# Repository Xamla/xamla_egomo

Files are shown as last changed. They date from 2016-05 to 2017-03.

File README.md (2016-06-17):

# xamla_egomo

### What is Xamla Egomo?

Egomo is an open-source research vision sensor developed at [Xamla](http://www.xamla.com/) for adaptive robotics research on a [Universal Robot UR5](http://www.universal-robots.com/) equipped with [Robotiq](http://robotiq.com/) end-of-arm technology. It integrates consumer cameras like the Logitech C920 and Structure IO and allows you to mount them on a robotic arm. It acts as a low-cost, 3D-printable reference smart-sensor device for our [ROSVITA](http://www.xamla.com/rosvita/) robot programming IDE which is currently under development (to be released in 2017).
For more information and product pictures visit the [egomo website](http://xamla.com/egomo).  

Video: Watch our UR5 robot [stacking duplos](https://www.youtube.com/watch?v=uo04vuXcwlw) using the Egomo sensor (source code of the demo can be found [here](/egomo_demos/duplo_stacking)).

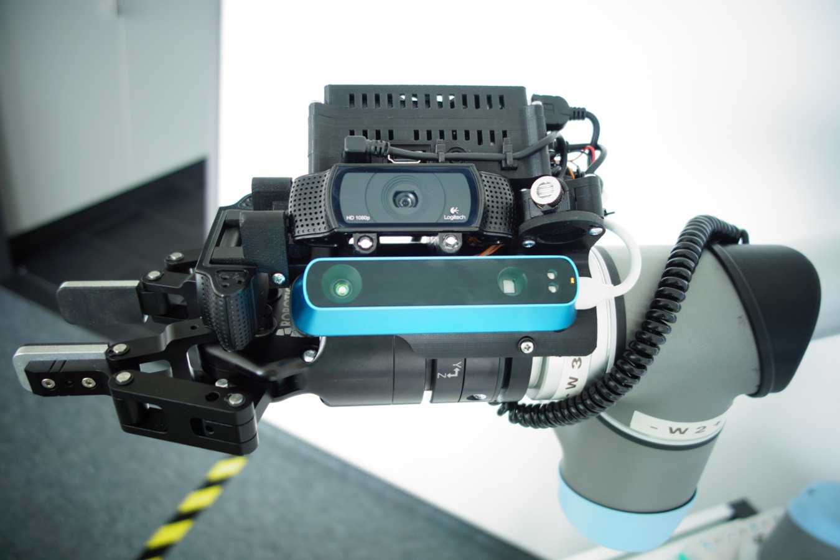
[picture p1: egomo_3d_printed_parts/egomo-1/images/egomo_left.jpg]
sensorhead1 Egomo sensor head side view, showing that the webcam can be mounten on the side as well as in the front.


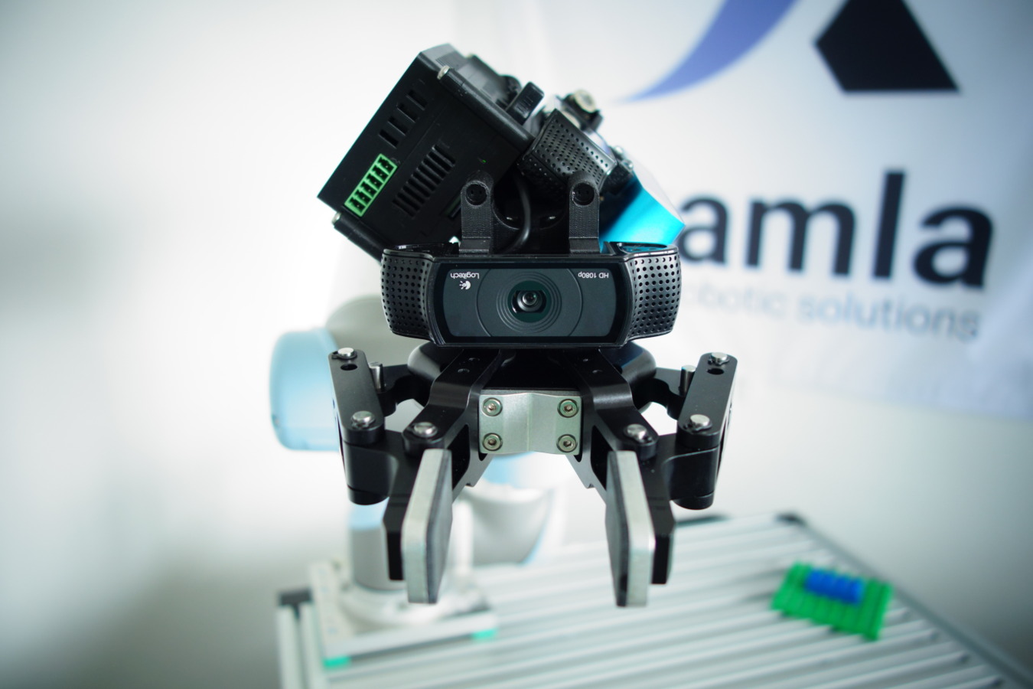
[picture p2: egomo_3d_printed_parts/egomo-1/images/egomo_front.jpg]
sensorhead2 Egomo sensor head front view


### Unique Features of Xamla Egomo

* 2D+3D: two side- and front view Logitech C920 cameras in combinaton with a structure IO depth sensor, ideal for RGB-D scans and visual servoing experiments
* NO CABLES: wireless connection of all sensors and and the gripper (no cabled device offers more available joint-configuration space)!
* ROS: the functionalty of all sensors + actuators is exposed as ROS nodes
* EASY: A Lua client library is included which allows to capture images and move the robot to capturing poses + demos are provided
* The IO-board allows to directly connect a Robotiq 2-Finger-Gripper and a Robotiq FT-300 force torque sensor to Egomo. It also has IO ports for laser, high-power white/IR LEDs, simple grippers or tactile sensors (e.g. force-sensitive resistors).
* Egomo seamlessly integrates with the [Torch](http://torch.ch/) machine-learning framework (e.g. for deep learning based image segmentation, object detection or advanced RL-experiments).

### Xamla Egomo sensor head ROS Package ###

This package is based on [LUA](https://www.lua.org/) with [Torch](http://torch.ch/) and the wrappers
[torch-ros](https://github.com/Xamla/torch-ros),  [torch-pcl](https://github.com/Xamla/torch-pcl)  and [torch-opencv](https://github.com/VisionLabs/torch-opencv).

This packages comprises (in alphabetical order):

  * [egomo_3d_printed_parts](/egomo_3d_printed_parts): STL files for printing the mounting parts and case of the Egomo sensor.
  * [egomo_demos](/egomo_demos): Demos showing the sensor in action (like pick and place objects).
  * [egomo_depthcam](/egomo_depthcam): Contains a ros-node for the Strucure-IO depth sensor.
  * [egomo_ioboard](/egomo_ioboard): Contains the specs and pinout of the Xamla IO board.
  * [egomo_msgs](/egomo_msgs): ROS Messages, Services, Actions in order to talk to Gripper, Force-Torque Sensor, RGB-Camera, Depth-Camera, Laser, LED
  * [egomo_node](/egomo_node): A ros-node which is responsible for the communication to the IO-Board (e.g. Gripper, Force-Torque, LEDs, Laser).
  * [egomo_pi_image](/egomo_pi_image): Describes the steps required to download and setup our fast booting Raspberry PI linux image.
  * [egomo_tools](/egomo_tools): A client library offering an easy to use interfaces to gripper, structure IO, webcam and the robot itself.
  * [egomo_ur5](/egomo_ur5): Contains URDF Robot description of the UR5 equipped with Egomo sensor head as well as launch files for e.g. gazebo.
  * [egomo_webcam](/egomo_webcam): Contains ros-node for the Logitech C920 webcam.
  * [xamla_egomo](/xamla_egomo) Metapackage

### Calibration ###

We offer an implemented calibration routine [on request](http://xamla.com/en/contact/index.html) as well as CAD-Files when you would like to adapt the sensor head for another robot. In 2017 we will offer [ROSVITA](http://xamla.com/en/rosvita/index.html) which brings a lot of features such as a convenient calibration routine (including full robot calibration).

### Get a pre-assembled Egomo device

You like the idea of open-source hardware but the process of buying parts, 3D printing, soldering, building etc. is too cumbersome and time-intensive for you and you would like to get a tested/working sensor head quickly?
As a convenient solution we offer a pre-assembled version of the Egomo sensor head with all parts installed and tested (good quality 3D printed parts made from ABS Ultrat, Logitech C920 Web-Cam (2x), Structure IO sensor, white LEDs (3x), IR LED, Raspberry Pi 3, Xamla IO-Board, shortened USB cables, a customized RPi operating system on a 16 GB class 10 microSD card and a 20mW 830nm IR line laser (depending on your country's import restrictions)) for EUR 1499 + shipping. If you are interested in this offer please contact us via [E-mail](mailto:egomo@xamla.com).

### Support / Contact ###

If you have any trouble please let us know by [creating an issue](https://github.com/Xamla/xamla_egomo/issues/new). Do not hesitate to contact us via [E-mail](mailto:egomo@xamla.com) for questions, feedback and suggestions. We look forward to hear from you!

To stay always up-to-date about our latest developments you can follow [@xamla on Twitter](https://twitter.com/xamla) or [subscribe](http://xamla.com/en/egomo) to our newsletter.

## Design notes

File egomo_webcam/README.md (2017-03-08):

*

This package provides an ROS interface to the Logitech C920 web camera. It uses video4linux for communication and therefore should work with other cameras supported by video4linux, too.

** Advertised Services

*** get\_new\_image
Grabs a new image from the camera. It is guaranteed that the image is recorded after this service is called. The image is provided in the camera raw format (uncompressed YUYV image in case of C920) and returned as a ROS [sensor_msgs/Image.msg](http://docs.ros.org/api/sensor_msgs/html/msg/Image.html) message.

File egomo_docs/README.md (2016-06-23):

The "index.html" visually describes the Xamla Egomo sensor head assembly. <br />
In more detail the following steps are described:

* Removal of old wrist joint cap and assembly of new one. 
* Dismantling of the Logitech camera. 
* Attachment of laser, Structure IO and Logitech camera to the printed base board. 
* Attachment of the Raspberry Pi 3 to the base board. 
* Attachment of force torque sensor, gripper and base board to the UR5. 
* Preparation of the Logitech camera for an alternative front connection with the base board.
* Alternative rotated attachment of the force torque sensor and gripper to the UR5.

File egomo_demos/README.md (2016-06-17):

# Demos for egomo sensor
This directory contains two demos that use the egomo sensor head.
- Clear Table
- Adaptive Duplo Stacking

### Clear Table
The robot identifies objects located on a table which it automatically collects and drops into a box ([Video](https://youtu.be/jR7Gnce9xus)).

### Adaptive Duplo Stacking
The robot detects freely positioned Duplo bricks on a table and stacks them on a visually measured target position ([Video](https://youtu.be/uo04vuXcwlw)).

## Calibration
These demos require very precise information about the geometric properties of the cameras ([intrinsic parameters](https://en.wikipedia.org/wiki/Camera_resectioning#Intrinsic_parameters)) and their mounting positions+orientations with respect to the tool center point (TCP) (hand-to-eye matrices). For an accurately working system these parameters have to be calibrated individually for each camera / egomo sensor. To run the demo without this complex calibration step, we added default values. Without proper calibration you should be able to see the basic behavior but not as precise as it is shown in the demo videos. 

A fully autonomous calibration procedure is in development. If you are interested to get the status or a preview version of the calibration that makes your UR5 + Egomo really accurate, please [contact us](mailto:egomo@xamla.com).

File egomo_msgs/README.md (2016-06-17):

# egomo_msgs Package #

This ROS package has to be built and installed on the Raspberry Pi which is part of the Egomo sensor 
as well as on any machine which makes use of these messages, actions and services. 
More information can be found in the [documentation of the egomo_node](https://github.com/Xamla/xamla_egomo/tree/master/egomo_node).

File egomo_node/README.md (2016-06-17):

# xamla_egomo_node #

## General Information ##

This node runs on the Raspberry Pi on the Egomo sensor and offers a ROS-service which offers ROS-actions to asynchronously control a connected gripper. Furthermore different topics are offered in order to get information about the gripper, force torque (FT) and inertial measurement unit (IMU).

### Overview  ###

 *  [Gripper message](#XamlaGripper)
 *  [Joint state of the gripper](#XamlaGripperJointState)
 *  [Force Torque message](#XamlaForceTorque)
 *  [Message IMU](#XamlaIOIMU)
 *  [Send commands to IO-Board](#SendCommand)
 *  [Action for gripper activation](#EgomoGripperActivate)
 *  [Action for setting gripper position](#EgomoGripperPos)
 *  [Troubleshooting](#Troubleshooting)

### Topic XamlaGripper ###

Publishes the state of the gripper using [XamlaGripper.msg](https://github.com/Xamla/xamla_egomo/tree/master/egomo_msgs/msg). Subscribe by typing the following in your terminal:

    rostopic echo /XamlaEgomo/XamlaGripper

Published data | type
---------|-----------
header   | [std_msgs/header](http://docs.ros.org/jade/api/std_msgs/html/msg/Header.html)
grip_force | float32
left_finger_force | float32
right_finger_force | float32
pos_fb | float32
uint8 | state
bool | object_gripped

### Topic XamlaGripperJointState ###

Publishes the state fo the gripper as joint state messages ([JointState](http://docs.ros.org/jade/api/sensor_msgs/html/msg/JointState.html)). Subscribe by typing the following in your terminal:

    rostopic echo /joint_states

Published data | type
---------|-----------
header   | [std_msgs/header](http://docs.ros.org/jade/api/std_msgs/html/msg/Header.html)
name     | string[]
position | float64[]
velocity | float64[]
effort | float64[]

### Topic XamlaForceTorque ###

Publishes sensor readings of the force torque sensor using [WrenchStamped](http://docs.ros.org/jade/api/geometry_msgs/html/msg/WrenchStamped.html). Subscribe by typing the following in your terminal: 

    rostopic echo /XamlaEgomo/XamlaForceTorque

Published data | type
---------|-----------
header   | [std_msgs/header](http://docs.ros.org/jade/api/std_msgs/html/msg/Header.html)
wrench   | [geometry_msgs/Wrench](http://docs.ros.org/jade/api/geometry_msgs/html/msg/Wrench.html)

### Topic XamlaIOIMU ###

Publishes sensor readings of the inertial measurement unit (IMU) using [AccelStamped](http://docs.ros.org/jade/api/geometry_msgs/html/msg/AccelStamped.html). Subscribe by typing the following in your terminal: 

    rostopic echo /XamlaEgomo/XamlaIOIMU

Published data | type
---------|-----------
header   | [std_msgs/header](http://docs.ros.org/jade/api/std_msgs/html/msg/Header.html)
accel   | [geometry_msgs/Accel](http://docs.ros.org/jade/api/geometry_msgs/html/msg/Accel.html)

### Service SendCommand ###

In order to send commands to the gripper this service was created ([SendCommand.srv](https://github.com/Xamla/xamla_egomo/tree/master/egomo_msgs/srv)). The following commands are available:

Command | value range | description
---------|-----------|--------------
reset   | 0 or 1 | Resets the gripper when value is set from 1 -> 0 (falling edge)
max_speed | 0-255 | Controls the speed of the gripper
max_force | 0-255 | Controls the force of the gripper
pos_cmd | 0.0-0.087 | Moves the gripper to the position (in m)
out0 | 0 or 1 | Turns on/off device at this board output (e.g. led, ir-led ord laser)
out1 | 0 or 1 | Turns on/off device at this board output (e.g. led, ir-led ord laser)
out2 | 0 or 1 | Turns on/off device at this board output (e.g. led, ir-led ord laser)

Notice that you should reset the gripper before use. During initialization the gripper moves. Here are two examples of valid calls of the service from the terminal.

    rosservice call /XamlaEgomo/SendCommand "reset" 0
    rosservice call /XamlaEgomo/SendCommand "pos_cmd" 0.05
    rosservice call /XamlaEgomo/SendCommand "out0" 0

### Action EgomoGripperActivate ###

This action can be used to activate/deactivate the gripper ([EgomoGripperActivate.action](https://github.com/Xamla/xamla_egomo/blob/master/egomo_msgs/action/EgomoGripperActivate.action)). It gives feedback about whether the gripper has been activated.

#### Goal ####

name | type | description
---------|-----------|---------------
activate   | bool | true to activate gripper - false to deactivate gripper

#### Feedback ####

name | type | description
---------|-----------|---------------
is_activated   | bool | true if gripper is activated - false if gripper is deactivated

#### Result ####

name | type | description
---------|-----------|---------------
is_activated   | bool | true if gripper is activated - false if gripper is deactivated

### Action EgomoGripperPos ###

This action can be used to send the gripper position commands ([EgomoGripperPos.action](https://github.com/Xamla/xamla_egomo/blob/master/egomo_msgs/action/EgomoGripperPos.action)). Furthermore the speed and the force can be set directly if needed. The feedback and the result contain the current position of the gripper and whether an object has been gripped.

#### Goal ####

name | type | description
---------|-----------|---------------
goal_pos   | float32 | The desired position in m (e.g. 0.0 for close or 0.087 for open)
set_speed_and_force | bool | If true the given speed and the force are set directly with the position command.
speed | uint8 | Speed of the gripper (0 is lowest, 255 is highest speed)
force | uint8 | Force of the gripper (0 is lowest, 255 is highest force)

#### Feedback ####

name | type | description
---------|-----------|---------------
pos_fb   | float32 | The current position of the gripper
object_gripped   | bool | True if an object has been gripped and false otherwise

#### Result ####

type | name | description
---------|-----------|---------------
pos_fb   | float32 | The current position of the gripper
object_gripped   | bool | True if an object has been gripped and false otherwise

## Troubleshooting FAQ

 - Q1: I get the error "No device could be found!!!".
 - A1: The IO-Board connected the the Raspberry Pi could not be found. Make sure that it is connected properly. Usually the IO-Board should be recognized by the Raspberry Pi as a device /dev/ttyACM0 or any other number.

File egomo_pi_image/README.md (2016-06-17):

# Setup the Raspberry Pi for Xamla Egomo

This how-to assumes you use a Linux PC and was tested with Ubuntu 14.04 and 16.04 but should work for other Linux distributions, too.
It describes how to setup the SD card for the Raspberry Pi and provides a short overview how to operate the system.

## Prepare the SD card for the Raspberry Pi

The egomo sensor image for the Raspberry Pi can be obtained from the [Xamla homepage](http://xamla.com/downloads/egomo-1/rpi/xamla-egomo_v1_0.tar.gz). It is based on `Raspbian Jessie Lite`, version `May 2016`. In addition to the default image it contains amongst others a Lua+Torch installation, a basic ROS Jade installation and the Xamla Egomo tools. The image is optimized for fast boot and operates on read only partitions to protect the file system in case of a power failure.

The image can be installed to any SD card supported by the PI with a size of at least 8 GB. To achieve a short boot time and good operation performance of the Pi we recommend using class 10 SD cards or better.

Checksums of the image:

	MD5: dcfa77735607cd9b82e2f022387f87f7  xamla-egomo_v1_0.tar.gz
	SHA256: 1cad057e50a2ecf666028fc2797ee1846d1c4cb6a63e0c153f497c6268f39edc  xamla-egomo_v1_0.tar.gz

### Copying the Image to the SD Card

These steps are very similar to the steps required to [setup the usual Raspberry Pi images](https://www.raspberrypi.org/documentation/installation/installing-images/linux.md):

* Download the [SD card image](http://xamla.com/downloads/egomo-1/rpi/xamla-egomo_v1_0.tar.gz)
  * Connect the (new) SD card with your computer (SD card slot or via an SD card reader)
  * Unmount all partitions of the SD card (e.g. unmount /dev/sdd1 if sdd is your SD card device name) if any partition got mounted automatically
  * Write the content of the .img file to the SD card, e.g.

		`sudo dd bs=4M if=/some/path/on/your/disk/xamla-egomo.img of=/dev/sdd`

	***IMPORTANT***: Make sure to provide the *correct device name* as parameter for `of`, not just one of the partitions.
	You will loose all data on the device. So, double-check if the device (/dev/sdd) is really the SD card.
  * Wait until `dd` has finished. This might take some time and you will not see any output during the operation.
	With a typical class 10 SD card, the copy process takes about 6 minutes.
  * Remove the SD card and reconnect it with your PC. You should see two partitions on the SD card:
	A small one called boot and a second one with a size of about 6 GB containing the root file system. If the partitions don't get mounted automatically, mount them manually. When the root partition of the SD card is mounted, continue with the next section.

### Adopt the Config Files for Your Network/ROS Environment

The partition on the SD card are mounted read-only during operation to protected the file system in case of power failure. Therefore a few more files then usual have to be adopted.

  * `/etc/hosts`: Adopt the hostname to your requirement
  * `/etc/hostname`: Replace `pi-xamla` with the same hostname you set in /etc/hosts
  * `/etc/resolv.conf`: Set the correct domain name and the IP address of at least one name server. Usually this file would be updated automatically but since we are running a read-only filesystem the file has been filled by hand.
  * `/etc/ros-config`: Set the `ROS_MASTER_URI` to the URI of the system running the roscore/master server
  * `/etc/ntp.conf`: If the Pi has no internet access, provide the address of at least one reachable NTP server. By default, the debian.pool NTP servers are used.
  * `/etc/wpa_supplicant/wpa_supplicant.conf` By default, the pi uses the on-board wireless adapter for network access. The SSID and the password for the WLAN has to be configured in this file. If you want to use the Ethernet port instead of wireless, edit `/etc/network/interfaces`.

## First Boot

Plug in the SD card to your Raspberry Pi and power it up.

  * Log in to the pi with username `pi` and password `xamla`. (either via network or via a directly connected keyboard/monitor)
  * Remount the partition in read-write mode. To comfortable switch between read-only and read-write mode, two aliases `ro` and `rw` are defined. Just type `rw` at the prompt to remount the partition as read-write.
  * Change the password for user pi with `passwd`.
  * You might want to regenerate the SSH server keys:

        sudo rm -v /etc/ssh/ssh_host_*
        sudo dpkg-reconfigure openssh-server

## Useful Commands

  * By default, three ROS nodes are started during the system boot. The status of the nodes can be checked with

        sudo systemctl status rosgripper.service
        sudo systemctl status roswebcam.service
        sudo systemctl status rosdepthcam.service

  * Rebuilding the catkin workspace: Switch to ~/catkin_ws and execute

        source /home/pi/catkin_ws/devel/setup.bash
        catkin_make -DCMAKE_INSTALL_PREFIX=/opt/ros/jade -DCMAKE_BUILD_TYPE=Release -DCMAKE_CXX_FLAGS=-O3 install

## Remote Logging

The current setup uses the busybox syslogd daemon. It get's configured via `/etc/default/busybox-syslogd`. Open the file
and edit the line starting with `SYSLOG_OPTS`. Comment the line `SYSLOG_OPTS="-C128"` and uncomment `SYSLOG_OPTS="-C128 -L -R host:port"`. Host and port have to be set to your remote logging host. If you use the default port 512, the port number can be omitted. Afterwards, restart the syslog daemon via `sudo systemctl restart busybox-syslogd`

On the remote logging host, uncomment/add following lines in `/etc/rsyslog.conf`

        # provides UDP syslog reception
        $ModLoad imudp
        $UDPServerRun 514
        # make rsyslog listen on all ip addresses, you could specify an address
        $UDPServerAddress 0.0.0.0

**WARNING** Configuring the remote logging this way both expose all logging messages of the Pi to all PCs in your network and exposes the logging host so that any computer in the network can send log messages to the logging host. Use this setup only in a trusted network.

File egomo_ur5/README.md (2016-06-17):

# Description of egomo_ur5 #

This package contains the kinematic chain of the full egomo_ur5 robotic setup (ur5 + force torque sensor + Robotiq gripper + egomo sensor) together with their visualization and collision models.

## General Information ##

Launch scripts are provided to start the robotic system with the URDF description
and the ros joint position controllers.

Start with real robot:

    roslaunch egomo_ur5 xamlaEgomo_ur5.launch

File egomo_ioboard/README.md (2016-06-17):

# xamla_ioboard
The Xamla IOBoard is the power supply and lowlevel IO interface of Xamla egomo.

### SPECS
- Cortex M4 CPU 72MHz
- 4x analog input 0-5V 12bit
- 3x digital output (5V 1A / 24V 1A, pwm capable)
- 6 axis IMU (MPU 6050)
- RGB LED 24bit
- 48V 1.5A input
- 5V 4A output (Sensors, RPi, ...)
- 24V 2A output (Gripper, FTS)
- USB 2.0 FS configuration port
- 2x RS485 UART max. 9Mbit/s
- 85x55mm

### PINOUT
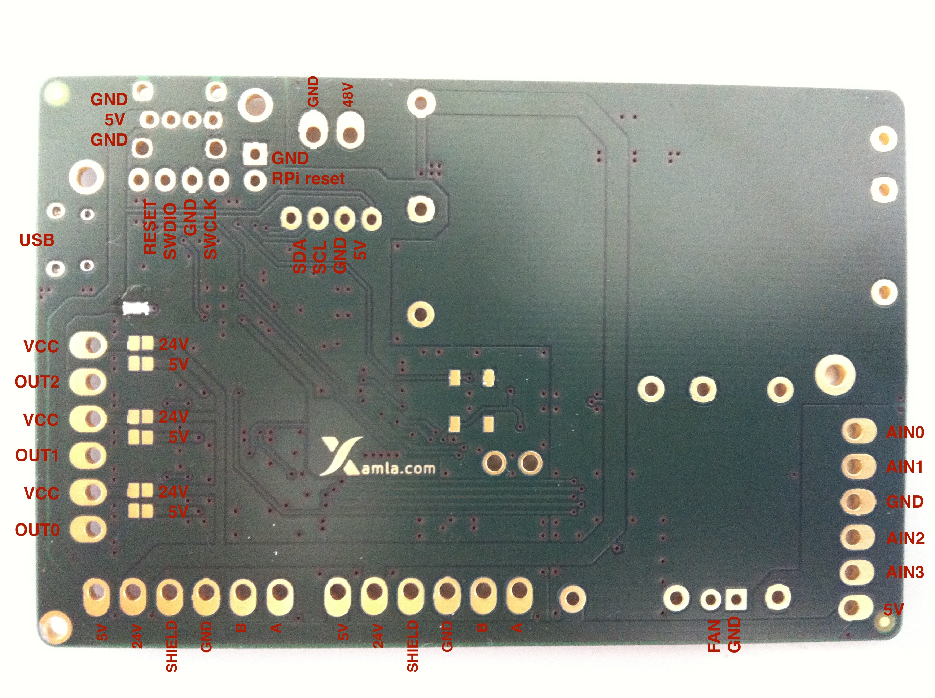
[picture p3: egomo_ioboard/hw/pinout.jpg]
ioboard_0_9_1 pinout IOBoard 0.9.1


### SCHEMATIC
[IOBoard 0.9.1 schematic](hw/io.pdf)

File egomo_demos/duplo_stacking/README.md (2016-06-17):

# Duplo Stacking Demo

## What is done?
This demo shows how to stack Duplo bricks that are placed randomly on a table. (A video of this demo is available on youtube https://youtu.be/uo04vuXcwlw ). The robot searches in a predefined area for a target brick that must be mounted on a Duplo base plate. If the target brick has been found, the robot moves to a predefined overview pose, acquires a depth image, makes a simple segmentation (object that is located above a plane), moves to a found duplo brick, acquires two rgb images and triangualtes the center position of the brick. Then the robot grips the brick and moves to the target position and stacks the brick.

## Assumptions
- The tables normal where bricks are located is (0,0,-1) (in robot base coordinates)
- Bricks are standard duplo bricks (2x4 height 19mm)
- hand-eye of depth sensor and rgb camera and their intrinsics are known
- The setup is: one brick on a base-plate as target position at a roughly known position
- bricks to be stacked are located on a flat surface 

## Package Requirements
- [torch-ros](http://github.com/xamla/torch-ros)
- [torch-opencv](https://github.com/VisionLabs/torch-opencv/)
- [torch-pcl](http://github.com/xamla/torch-pcl)
- [egomo_tools](https://github.com/Xamla/xamla_egomo/tree/master/egomo_tools)

## Code
The code consists of three parts:
- robot movement and gripping operations ([adaptiveStackingDuplo.lua](adaptiveStackingDuplo.lua))
- detection of duplo bricks ([duploDetection.lua](duploDetection.lua))
- segmentation of depth image ([ObjectsOnPlaneSegmentation.lua](ObjectsOnPlaneSegmentation.lua))

### duploDetection.lua
Idea: The knobs of the Duplo are detected in each image individually by a opencv Hough Circle detection, then circles are matched using the known fundamental matrix between the images, and triangulated. To avoid matching errors an initial guess of the z-Value (in robot coordinates) of the top edge is provided by the user. Finally, the orientation and the center of the duplo is calculated

### adaptiveStackingDuplo.lua
Idea: (Workflow can be found in [main function](https://github.com/Xamla/xamla_egomo/blob/master/egomo_demos/duplo_stacking/adaptiveStackingDuplo.lua#L279))
- Robot moves to a predefined target position (positions are defined in `CreatePoses()`), 
- the target is scanned (`ScanTargetPosition()`)
- The robot moves to an overview pose and grabs an image
- Then objects are segmented laying on the table (`segmentation:process(....)`)
- Robot moves wo the Duplo such that the camera is located above the Duplo (`ScanDuplo()`)
- If the Duplo brick is found the robot moves to a pre-pick position
- Then it gripps the brick
- Moves to target position (pre-Place position and then place postion)
- Opens the gripper
- Then the whole process is repeated

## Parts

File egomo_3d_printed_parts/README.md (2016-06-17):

# 3D-Print Your Xamla Egomo Sensor Head

You can use your favorite 3D printing service to produce the parts of an Egomo sensor head. For local 3D printing we can recommend [3D hubs](https://www.3dhubs.com/). For best quality prints (guaranteed to be accurately fitting) you can also order the parts directly [from us](mailto:egomo@xamla.com) or from our local 3D printing partner [UrbanMarker](http://urbanmaker.de/) (located in Münster, Germany).

## Available Models

- [Egomo-1](egomo-1/README.md)

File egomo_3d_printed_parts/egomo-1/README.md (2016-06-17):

# STL files for 3D printing of Egomo-1

## Product Pictures

We took some photos to give you an impression how the finished sensor head looks when it is mounted on a UR5.

Egomo left view
Egomo front view
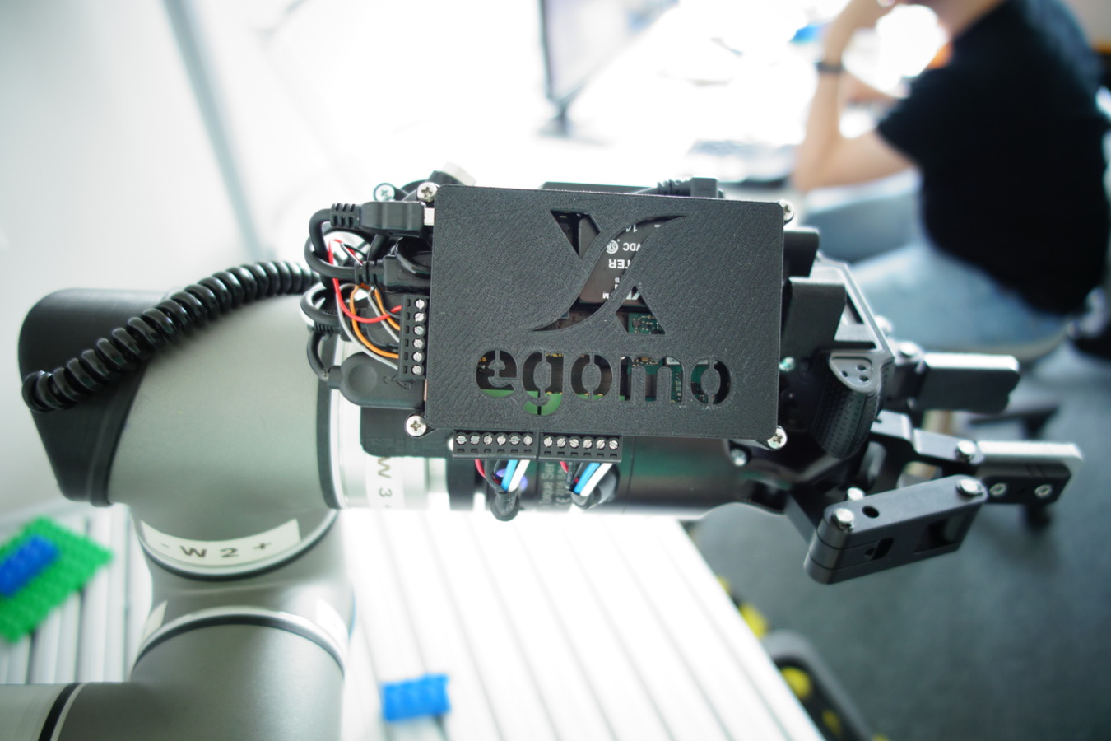
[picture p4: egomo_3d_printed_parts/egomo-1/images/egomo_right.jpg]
Egomo right view

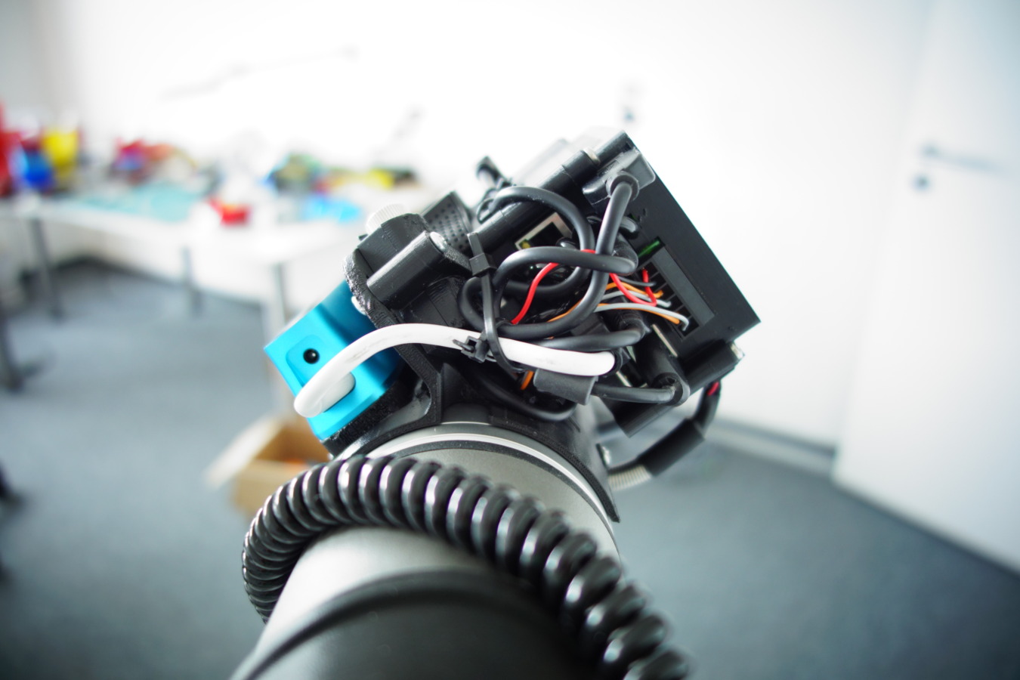
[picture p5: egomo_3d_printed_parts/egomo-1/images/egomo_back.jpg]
Egomo back view

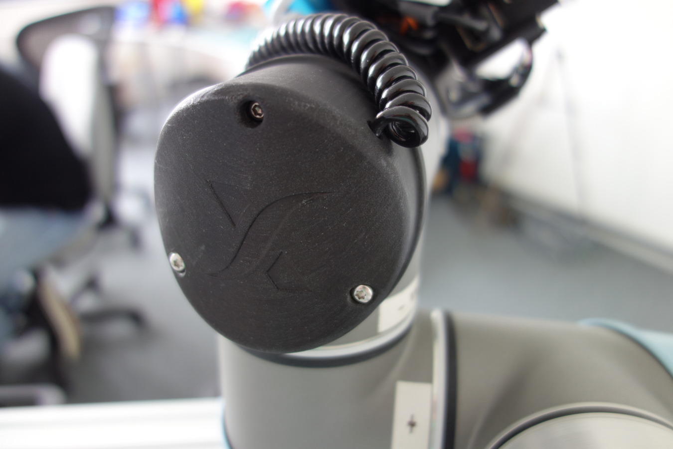
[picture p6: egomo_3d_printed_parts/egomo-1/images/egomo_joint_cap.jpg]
Egomo joint cap


## Multi-use Options

There are many ways to use the Egomo 3D models for your robotic research experiments:

Here are some ideas:

1. Obviously you can build the fully featured Egomo-1 sensor, optionally with or without enclosure for the Raspberry Pi or front-camarea mount.
2. Just use the coupling + base plate as a camera mount (conventionally cabled).
3. Use the RPi+IO-Board enclosure stand-alone as a remote ROS sensor-node or smart camera (e.g. to monitor the roboter scene from a fixed RGB-D camera). 

## Parts

The 3D printing file set of the Egomo-1 sensor consinsts of the following parts:

- coupling: [xamla_mount_flange.stl](xamla_mount_flange.stl)
- base-plate: [xamla_mount_base.stl](xamla_mount_base.stl)
- custom joint cap: [xamla_cap_hole.stl](xamla_cap_hole.stl)
- C920 side mount: [xamla_mount_c920_left.stl](xamla_mount_c920_left.stl), [xamla_mount_c920_right.stl](xamla_mount_c920_right.stl)
- C920 front mount: [xamla_mount_c920_front_0_left.stl](xamla_mount_c920_front_0_left.stl), [xamla_mount_c920_front_0_right.stl](xamla_mount_c920_front_0_right.stl) 
- Line-Laser mount: [xamla_mount_laser_bottom.stl](xamla_mount_laser_bottom.stl), [xamla_mount_laser_top.stl](xamla_mount_laser_top.stl)
- Raspberry Pi + IO Board enclosure: [xamla_mount_rpi_bottom.stl](xamla_mount_rpi_bottom.stl), [xamla_mount_rpi_middle.stl](xamla_mount_rpi_middle.stl),  [xamla_mount_rpi_top.stl](xamla_mount_rpi_top.stl)

Additionally we provide the file [xamla_cap.stl](xamla_cap.stl) which is a simple version of our modified joint cap without a hole for the power cable. It might be useful if you just want to fix a kinematic problem (collision) of the original UR5 joint cap that prevents the robot from freely rotating in all situations.

## Adaption to other Robots

If you are a robotics researcher and you want to customize the Egomo 3D parts to your special requirements or adapt it to a different robot we can provide you the original CAD files on request. Please get in touch with us via [E-Mail](mailto:egomo@xamla.com).

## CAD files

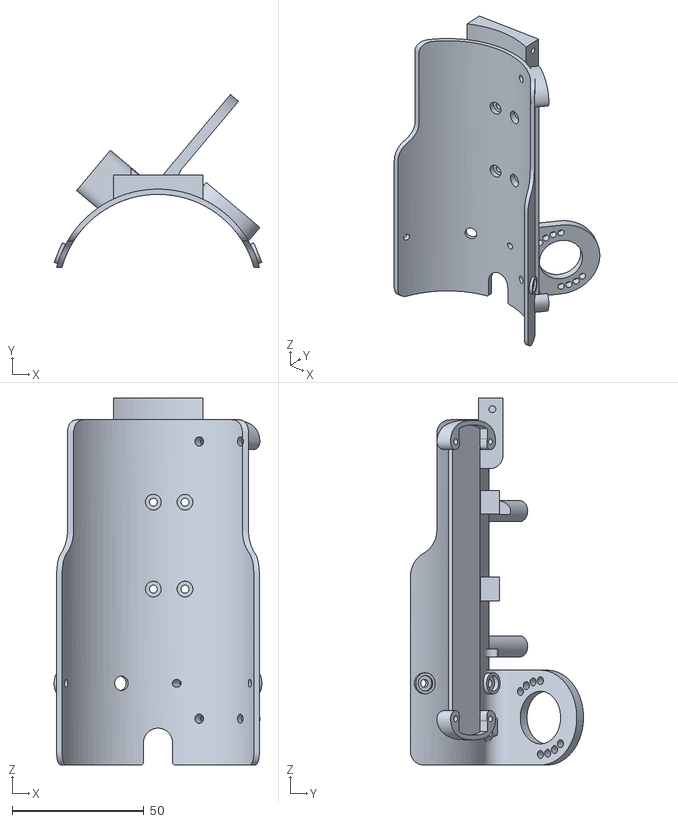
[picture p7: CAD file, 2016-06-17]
egomo_3d_printed_parts/egomo-1/xamla_mount_base.stl
78.8 x 65.6 x 139.3

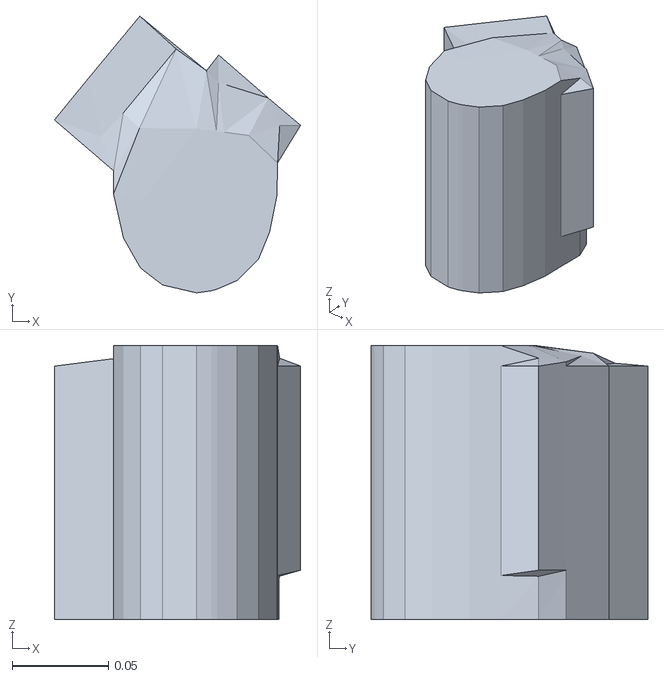
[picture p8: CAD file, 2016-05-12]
egomo_ur5/meshes/egomo-1/collision/egomo-1.stl
0.128 x 0.144 x 0.143

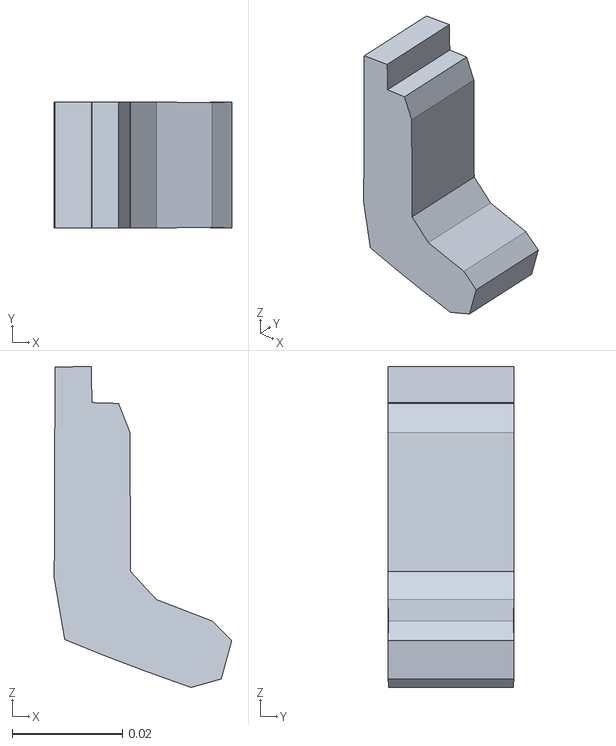
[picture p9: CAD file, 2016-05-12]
egomo_ur5/meshes/robotiq-2-finger-85/collision/gripper_finger_left_4.stl
0.0322 x 0.0228 x 0.0581

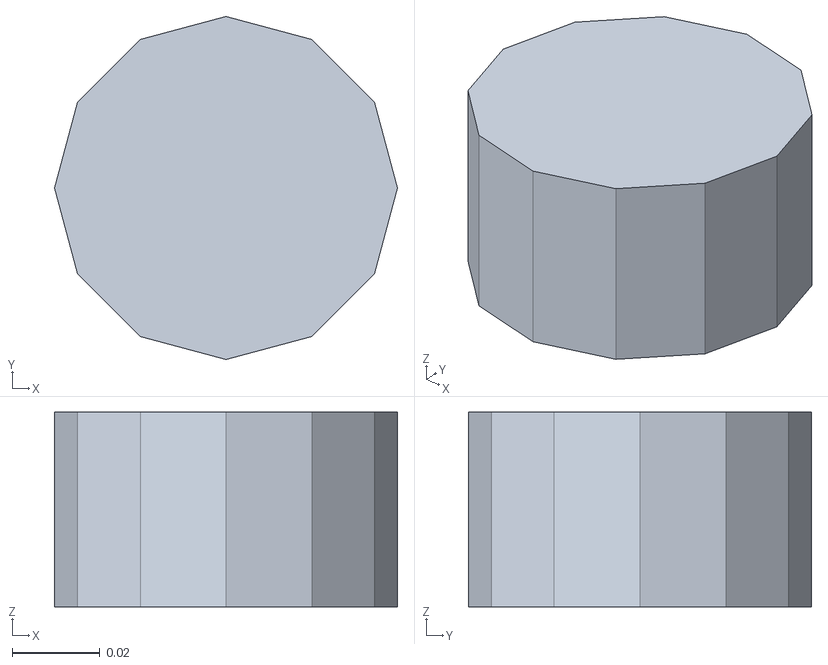
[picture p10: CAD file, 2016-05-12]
egomo_ur5/meshes/robotiq-ft300/collision/ft300.stl
0.0782 x 0.0782 x 0.0443

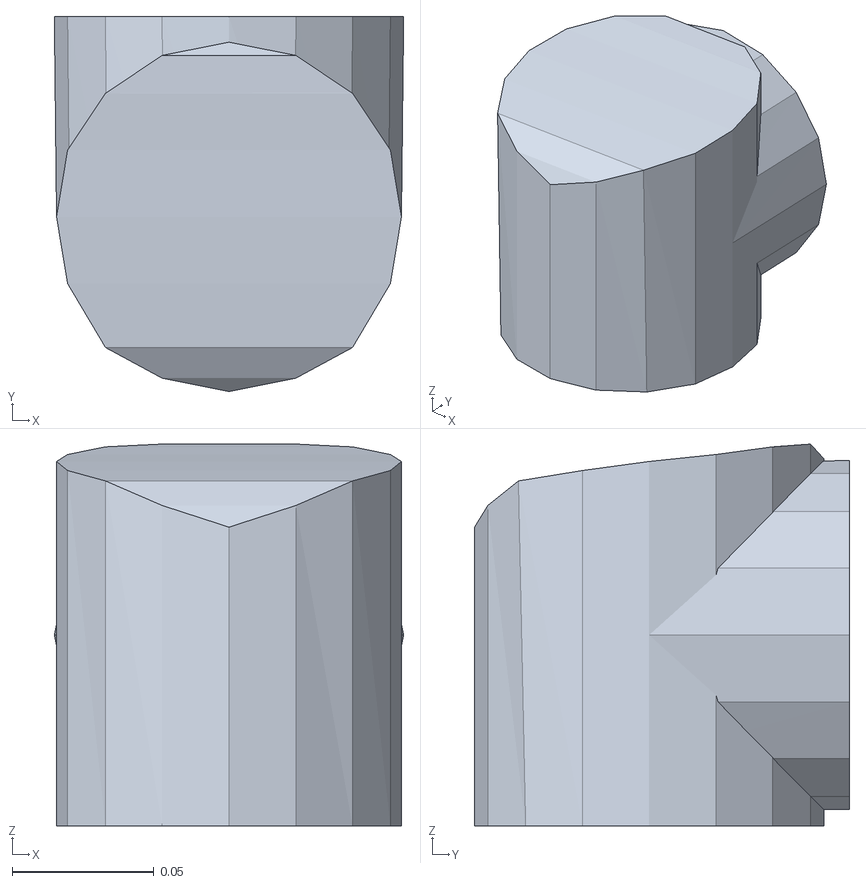
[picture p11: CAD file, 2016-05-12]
egomo_ur5/meshes/ur5/collision/shoulder.stl
0.123 x 0.132 x 0.135

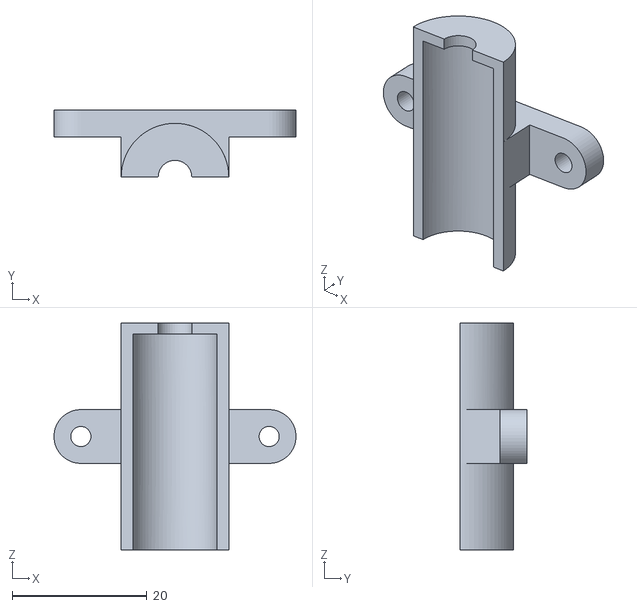
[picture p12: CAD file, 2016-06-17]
egomo_3d_printed_parts/egomo-1/xamla_mount_laser_top.stl
36.0 x 10.0 x 33.7

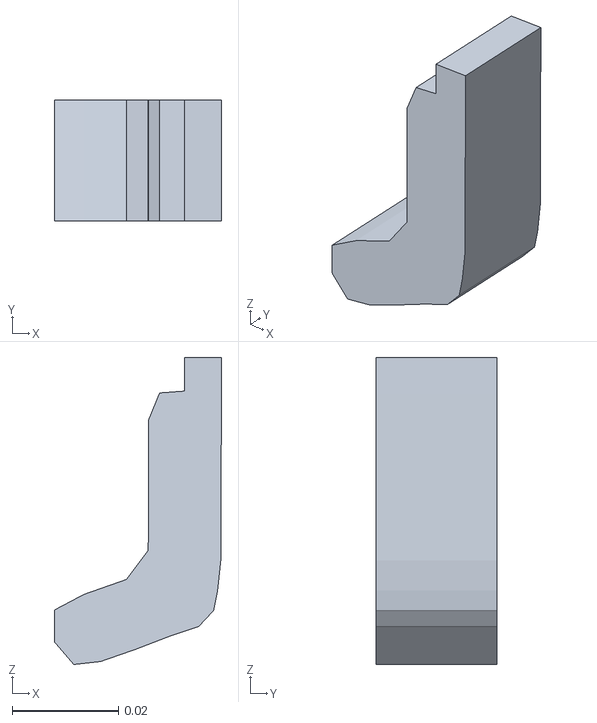
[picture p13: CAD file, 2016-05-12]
egomo_ur5/meshes/robotiq-2-finger-85/collision/gripper_finger_right_4.stl
0.0314 x 0.0228 x 0.0578

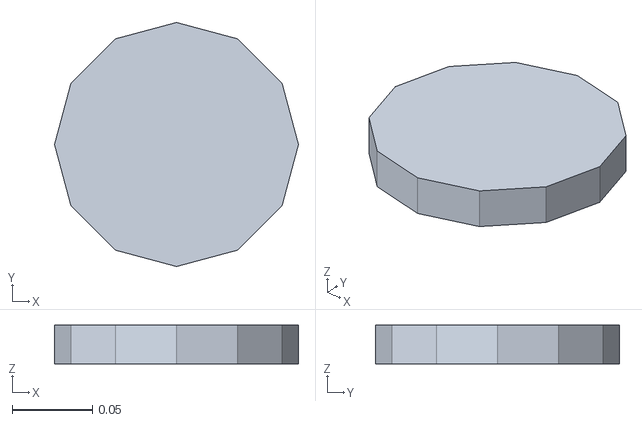
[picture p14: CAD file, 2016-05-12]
egomo_ur5/meshes/ur5/collision/base.stl
0.152 x 0.152 x 0.0242

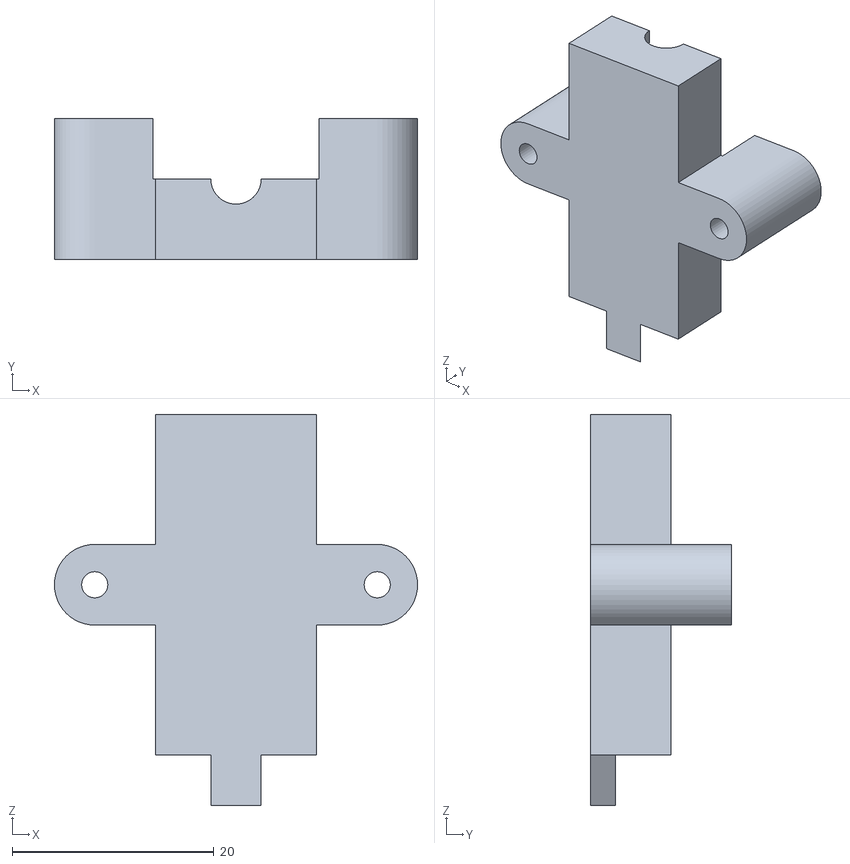
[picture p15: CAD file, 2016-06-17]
egomo_3d_printed_parts/egomo-1/xamla_mount_laser_bottom.stl
36.0 x 14.0 x 38.7

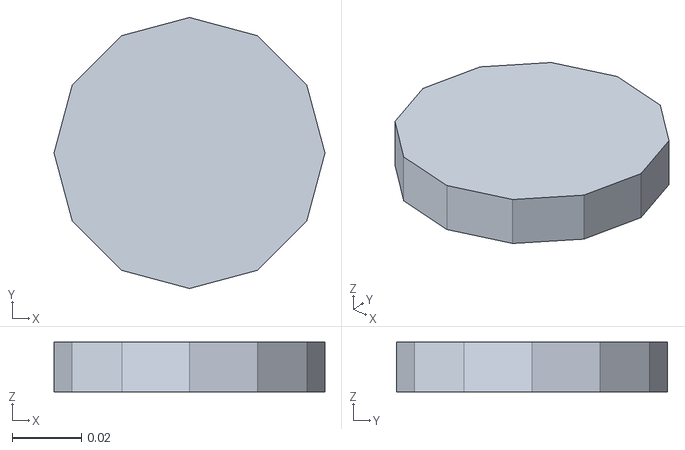
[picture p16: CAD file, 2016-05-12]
egomo_ur5/meshes/robotiq-2-finger-85/collision/gripper_coupling.stl
0.0781 x 0.0781 x 0.0143

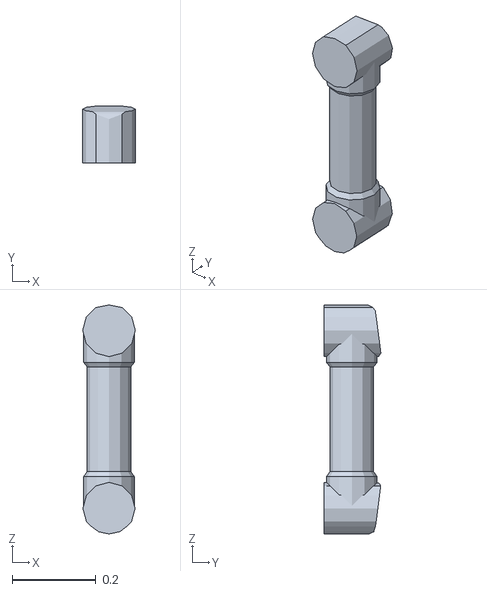
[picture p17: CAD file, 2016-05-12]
egomo_ur5/meshes/ur5/collision/upper_arm.stl
0.126 x 0.136 x 0.547

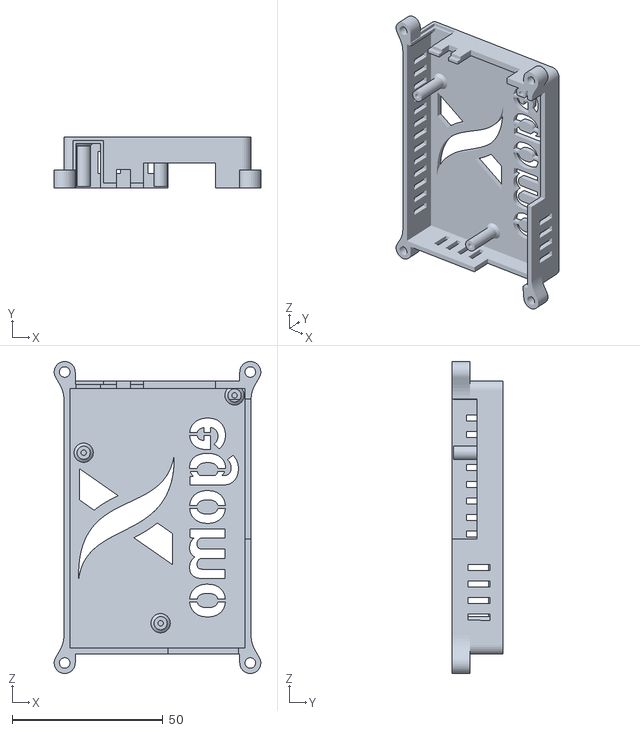
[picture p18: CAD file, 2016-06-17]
egomo_3d_printed_parts/egomo-1/xamla_mount_rpi_top.stl
68.5 x 16.9 x 103.4

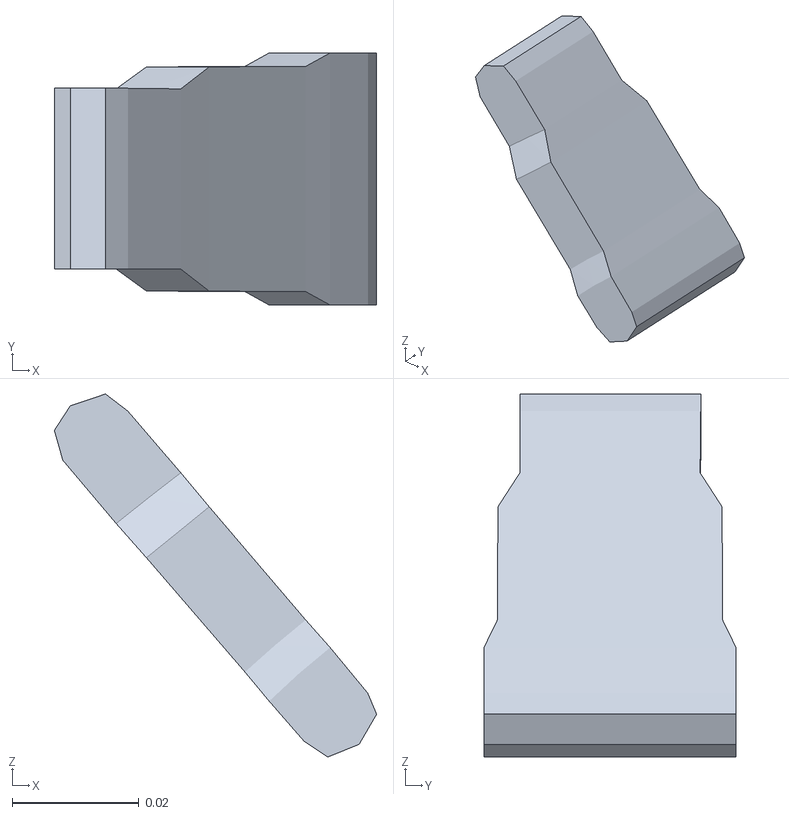
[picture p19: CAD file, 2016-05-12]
egomo_ur5/meshes/robotiq-2-finger-85/collision/gripper_finger_right_3.stl
0.0509 x 0.0398 x 0.0573

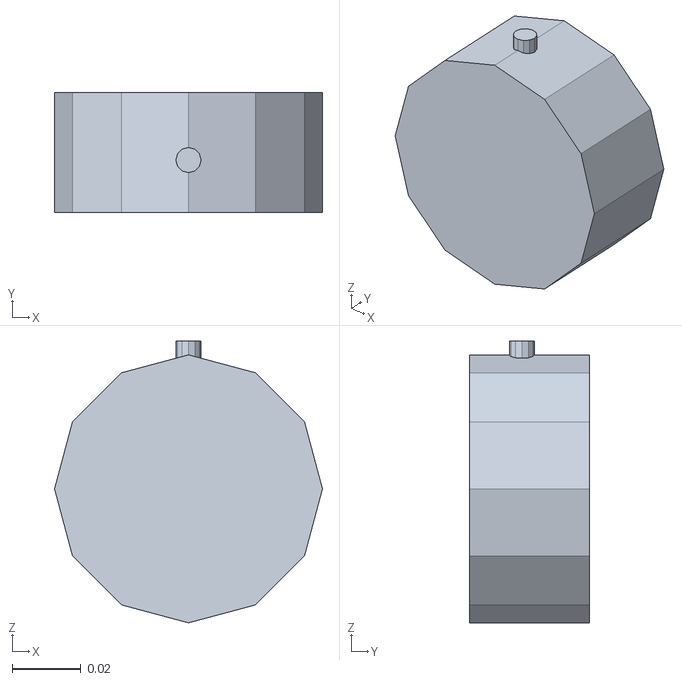
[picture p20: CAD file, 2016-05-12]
egomo_ur5/meshes/ur5/collision/wrist_3.stl
0.0781 x 0.0349 x 0.0821

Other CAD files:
egomo_3d_printed_parts/egomo-1/xamla_mount_rpi_middle.stl
egomo_ur5/meshes/robotiq-2-finger-85/collision/gripper_finger_left_1.stl
egomo_ur5/meshes/ur5/collision/wrist_2.stl
egomo_3d_printed_parts/egomo-1/xamla_mount_rpi_bottom.stl
egomo_3d_printed_parts/egomo-1/xamla_cap.stl
egomo_3d_printed_parts/egomo-1/xamla_cap_hole.stl
egomo_3d_printed_parts/egomo-1/xamla_mount_c920_front_0_left.stl
egomo_3d_printed_parts/egomo-1/xamla_mount_c920_front_0_right.stl
egomo_3d_printed_parts/egomo-1/xamla_mount_c920_left.stl
egomo_3d_printed_parts/egomo-1/xamla_mount_c920_right.stl
egomo_3d_printed_parts/egomo-1/xamla_mount_flange.stl
egomo_ur5/meshes/robotiq-2-finger-85/collision/gripper_base.stl
egomo_ur5/meshes/robotiq-2-finger-85/collision/gripper_finger_left_2.stl
egomo_ur5/meshes/robotiq-2-finger-85/collision/gripper_finger_left_3.stl
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

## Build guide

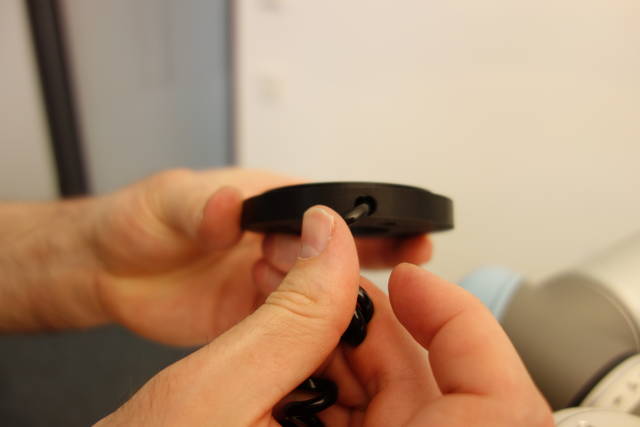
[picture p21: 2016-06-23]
egomo_docs/Egomo_Installation/small-DSC03203.JPG

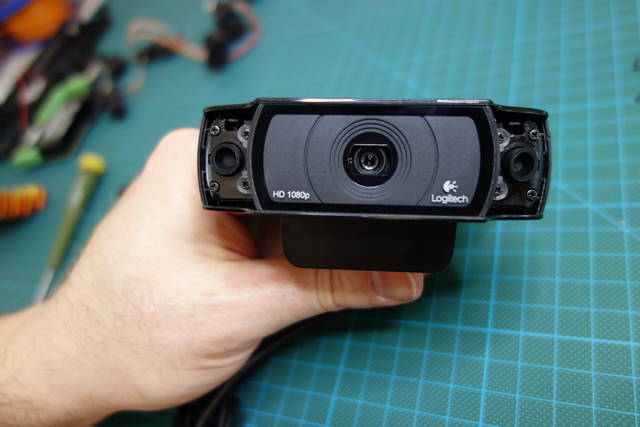
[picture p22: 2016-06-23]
egomo_docs/Egomo_Installation/small-DSC03115.JPG

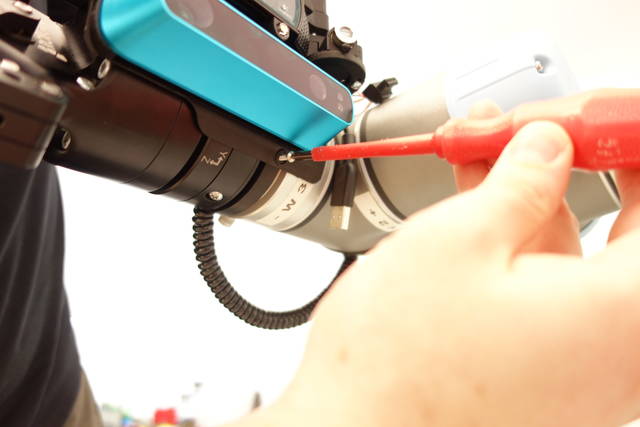
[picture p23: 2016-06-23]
egomo_docs/Egomo_Installation/small-DSC03222.JPG

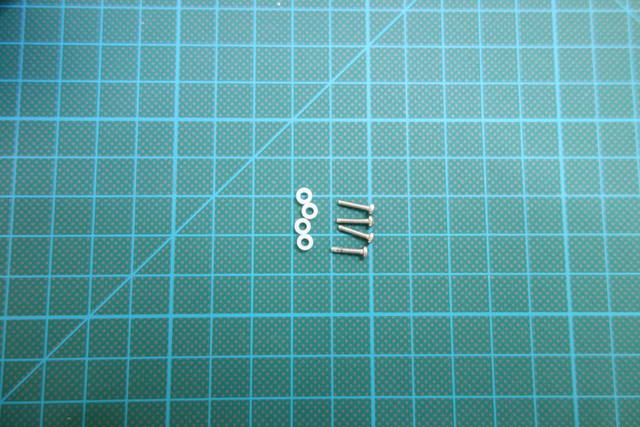
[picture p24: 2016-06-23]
egomo_docs/Egomo_Installation/small-DSC03189.JPG

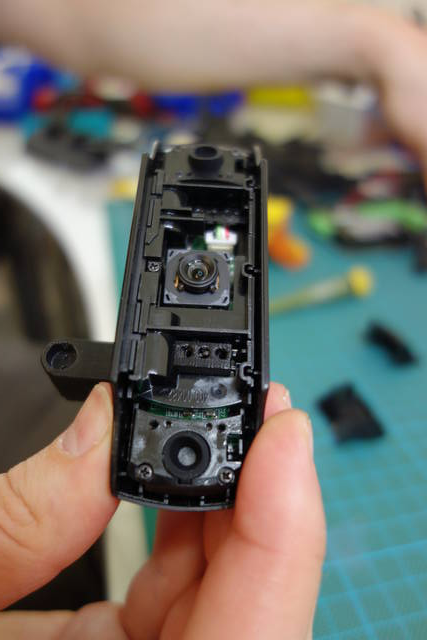
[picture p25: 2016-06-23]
egomo_docs/Egomo_Installation/small-DSC03126.JPG

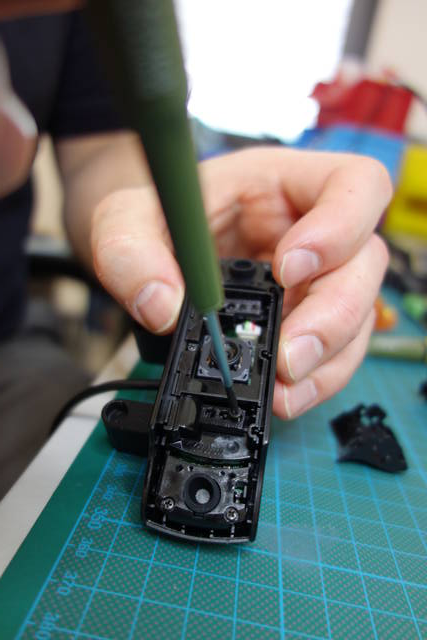
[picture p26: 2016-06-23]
egomo_docs/Egomo_Installation/small-DSC03130.JPG

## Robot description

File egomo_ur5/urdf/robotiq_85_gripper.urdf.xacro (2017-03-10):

<?xml version="1.0"?>
<robot name="robotiq_85_gripper" xmlns:xacro="http://ros.org/wiki/xacro">
    <xacro:macro name="robotiq_85_gripper" params="prefix parent *origin">
        <link name="${prefix}robotiq_85_coupling">
            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
        </link>
        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
        <joint name="${prefix}gripper_to_flange" type="fixed">
            <parent link="${parent}" />
            <child link="${prefix}robotiq_85_coupling" />
            <xacro:insert_block name="origin" />
        </joint>
        <joint name="${prefix}robotiq_85_base_joint" type="fixed">
            <parent link="${prefix}robotiq_85_coupling" />
            <child link="robotiq_85_base" />
            <origin xyz="0 0 0.0109" rpy="0 0 0" />
            <xacro:insert_block name="origin" />
        </joint>
        <link name="${prefix}robotiq_85_base">
            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
        </link>
        <link name="${prefix}robotiq_85_finger_right_1">
            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
        </link>
        <link name="${prefix}robotiq_85_finger_right_2">
            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
        </link>
        <link name="${prefix}robotiq_85_finger_right_3">
            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
        </link>
        <link name="${prefix}robotiq_85_finger_right_4">
            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
        </link>
        <link name="${prefix}robotiq_85_finger_left_1">
            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
        </link>
        <link name="${prefix}robotiq_85_finger_left_2">
            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
        </link>
        <link name="${prefix}robotiq_85_finger_left_3">
            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
        </link>
        <link name="${prefix}robotiq_85_finger_left_4">
            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
        </link>
        <joint name="${prefix}robotiq_85_finger_right_1_joint" type="revolute">
            <parent link="${prefix}robotiq_85_base" />
            <child link="${prefix}robotiq_85_finger_right_1" />
            <axis xyz="0 -1 0" />
            <origin rpy="0 0 0" xyz="0.0305864 0 0.0549191" />
            <limit effort="1000" lower="0" upper="0.811" velocity="2.0" />
        </joint>
        <joint name="${prefix}robotiq_85_finger_right_2_joint" type="fixed">
            <parent link="${prefix}robotiq_85_finger_right_1" />
            <child link="${prefix}robotiq_85_finger_right_2" />
            <axis xyz="0 1 0" />
            <origin rpy="0 0 0" xyz="0.0315367 0 -0.0037599" />
        </joint>
        <joint name="${prefix}robotiq_85_finger_right_3_joint" type="revolute">
            <parent link="${prefix}robotiq_85_base" />
            <child link="${prefix}robotiq_85_finger_right_3" />
            <axis xyz="0 1 0" />
            <origin rpy="0 0 0" xyz="0.0127161 0 0.0613987" />
            <limit effort="1000" lower="0" upper="0.811" velocity="2.0" />
            <mimic joint="robotiq_85_finger_right_1_joint" multiplier="-1" offset="0" />
        </joint>
        <joint name="${prefix}robotiq_85_finger_right_4_joint" type="revolute">
            <parent link="${prefix}robotiq_85_finger_right_3" />
            <child link="${prefix}robotiq_85_finger_right_4" />
            <axis xyz="0 1 0" />
            <origin rpy="0 0 0" xyz="0.0371331 0 0.0434428" />
            <mimic joint="${prefix}robotiq_85_finger_right_1_joint" multiplier="1" offset="0" />
            <limit effort="1000" lower="-0.811" upper="0" velocity="2.0" />
        </joint>
        <joint name="${prefix}robotiq_85_finger_left_1_joint" type="revolute">
            <parent link="robotiq_85_base" />
            <child link="${prefix}robotiq_85_finger_left_1" />
            <axis xyz="0 1 0" />
            <origin rpy="0 0 0" xyz="-0.0305864 0 0.0549191" />
            <mimic joint="${prefix}robotiq_85_finger_right_1_joint" multiplier="1" offset="0" />
            <limit effort="1000" lower="-0.811" upper="0" velocity="2.0" />
        </joint>
        <joint name="${prefix}robotiq_85_finger_left_2_joint" type="fixed">
            <parent link="${prefix}robotiq_85_finger_left_1" />
            <child link="${prefix}robotiq_85_finger_left_2" />
            <axis xyz="0 1 0" />
            <origin rpy="0 0 0" xyz="-0.0315367 0 -0.0037599" />
        </joint>
        <joint name="${prefix}robotiq_85_finger_left_3_joint" type="revolute">
            <parent link="${prefix}robotiq_85_base" />
            <child link="${prefix}robotiq_85_finger_left_3" />
            <axis xyz="0 1 0" />
            <origin rpy="0 0 0" xyz="-0.0127161 0 0.0613987" />
            <mimic joint="${prefix}robotiq_85_finger_right_1_joint" multiplier="1" offset="0" />
            <limit effort="1000" lower="-0.811" upper="0" velocity="2.0" />
        </joint>
        <joint name="${prefix}robotiq_85_finger_left_4_joint" type="revolute">
            <parent link="${prefix}robotiq_85_finger_left_3" />
            <child link="${prefix}robotiq_85_finger_left_4" />
            <axis xyz="0 1 0" />
            <origin rpy="0 0 0" xyz="-0.0371331 0 0.0434428" />
            <mimic joint="${prefix}robotiq_85_finger_right_1_joint" multiplier="-1" offset="0" />
            <limit effort="1000" lower="0" upper="0.811" velocity="2.0" />
        </joint>
        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
    </xacro:macro>
</robot>

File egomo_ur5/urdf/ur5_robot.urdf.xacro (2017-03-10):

<?xml version="1.0"?>
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
<robot name="ur5" xmlns:xacro="http://ros.org/wiki/xacro">
<xacro:include filename="$(find egomo_ur5)/urdf/default_ur5_DH_parameters.xacro" />

    
   
    <xacro:property name="pi" value="3.1415926535898" />
    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
    <xacro:property name="base_mass" value="4.0" />
    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
    <xacro:property name="shoulder_mass" value="3.7000" />
    <xacro:property name="upper_arm_mass" value="8.3930" />
    <xacro:property name="forearm_mass" value="2.2750" />
    <xacro:property name="wrist_1_mass" value="1.2190" />
    <xacro:property name="wrist_2_mass" value="1.2190" />
    <xacro:property name="wrist_3_mass" value="0.1879" />
    <xacro:property name="shoulder_cog" value="0.0 0.00193 -0.02561" />
    <xacro:property name="upper_arm_cog" value="0.0 -0.024201 0.2125" />
    <xacro:property name="forearm_cog" value="0.0 0.0265 0.11993" />
    <xacro:property name="wrist_1_cog" value="0.0 0.110949 0.01634" />
    <xacro:property name="wrist_2_cog" value="0.0 0.0018 0.11099" />
    <xacro:property name="wrist_3_cog" value="0.0 0.001159 0.0" />

    
    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
    <xacro:property name="shoulder_offset" value="0.13585" />
    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
    <xacro:property name="elbow_offset" value="0.1197" />
    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
    <xacro:property name="shoulder_height" value="${ur5_d1}" />
    <xacro:property name="upper_arm_length" value="${-ur5_a2}" />
    <xacro:property name="forearm_length" value="${-ur5_a3}" />
    <xacro:property name="wrist_1_length" value="${ur5_d4 + shoulder_offset+ elbow_offset}" />
    <xacro:property name="wrist_2_length" value="${ur5_d5}" />
    <xacro:property name="wrist_3_length" value="${ur5_d6}" />
    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
    <xacro:property name="shoulder_radius" value="0.060" />
    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
    <xacro:property name="upper_arm_radius" value="0.054" />
    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
    <xacro:property name="elbow_radius" value="0.060" />
    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
    <xacro:property name="forearm_radius" value="0.040" />
    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
    <xacro:property name="wrist_radius" value="0.045" />
    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
<xacro:macro name="ur5" params="prefix parent *origin">
    <joint name="world_joint" type="fixed">
        <parent link="${parent}" />
        <child link="base_link" />
        <xacro:insert_block name="origin" />
    </joint>
    <link name="base_link">
        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
        <inertial>
            <mass value="4.0" />
            <origin rpy="0 0 0" xyz="0.0 0.0 0.0" />
            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
        </inertial>
    </link>
    <joint name="shoulder_pan_joint" type="revolute">
        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
        <parent link="base_link" />
        <child link="shoulder_linka" />
        <origin rpy="0.0 0.0 ${theta_1}" xyz="0.0 0.0 ${ur5_d1}" />
        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
        <axis xyz="0 0 1" />
        <limit effort="150.0" lower="-3.14159265" upper="3.14159265" velocity="3.15" />
        <dynamics damping="0.0" friction="0.0" />
    </joint>
    <link name="shoulder_linka">
        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
        <inertial>
            <mass value="3.7" />
            <origin rpy="0 0 0" xyz="0.0 0.0 0.0" />
            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
        </inertial>
    </link>
    <joint name="shoulder_pan_joint_F" type="fixed">
        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
        <parent link="shoulder_linka" />
        <child link="shoulder_link" />
        <origin rpy="${alpha_1} 0.0 0.0" xyz="${ur5_a1} 0.0 0.0" />
    </joint>
    <link name="shoulder_link">
        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
        <inertial>
            <origin xyz="0 0 0" rpy="0 0 0" />
            <mass value="1" />
            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
        </inertial>
    </link>
    <joint name="shoulder_lift_joint" type="revolute">
        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
        <parent link="shoulder_link" />
        <child link="upper_arm_linka" />
        <origin rpy="0.0 0.0 ${theta_2}" xyz="0.0 0.0 ${ur5_d2}" />
        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
        <axis xyz="0 0 -1" />
        <limit effort="150.0" lower="-3.14159265" upper="-0.1" velocity="3.15" />
        <dynamics damping="0.0" friction="0.0" />
    </joint>
    <link name="upper_arm_linka">
        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
        <inertial>
            <mass value="8.393" />
            <origin rpy="0 0 0" xyz="0.0 0.0 0.28" />
            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
        </inertial>
    </link>
    <joint name="upper_arm_link_F" type="fixed">
        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
        <parent link="upper_arm_linka" />
        <child link="upper_arm_link" />
        <origin rpy="${alpha_2} 0.0 0.0" xyz="${ur5_a2} 0.0 0.0 " />
    </joint>
    <link name="upper_arm_link">
        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
        <inertial>
            <origin xyz="0 0 0" rpy="0 0 0" />
            <mass value="1" />
            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
        </inertial>
    </link>
    <joint name="elbow_joint" type="revolute">
        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
        <parent link="upper_arm_link" />
        <child link="forearm_linka" />
        <origin rpy="0.0 0.0 ${theta_3}" xyz="0.0 0.0 ${ur5_d3}" />
        <axis xyz="0 0 -1" />
        <limit effort="150.0" lower="-3" upper="3" velocity="3.15" />
        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
        <dynamics damping="0.0" friction="0.0" />
    </joint>
    <link name="forearm_linka">
        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
        <inertial>
            <mass value="2.275" />
            <origin rpy="0 0 0" xyz="0.0 0.0 0.25" />
            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
        </inertial>
    </link>
    <joint name="elbow_joint_F" type="fixed">
        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
        <parent link="forearm_linka" />
        <child link="forearm_link" />
        <origin rpy="${alpha_3} 0.0 0.0" xyz="${ur5_a3} 0.0 0.0" />
    </joint>
    <link name="forearm_link">
        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
        <inertial>
            <origin xyz="0 0 0" rpy="0 0 0" />
            <mass value="1" />
            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
        </inertial>
    </link>
    <joint name="wrist_1_joint" type="revolute">
        <parent link="forearm_link" />
        <child link="wrist_1_linka" />
        <origin xyz="0.0 0.0 ${ur5_d4}" rpy="0.0 0.0 ${theta_4}" />
        <axis xyz="0 0 -1" />
        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
        <limit effort="28.0" lower="-${pi}" upper="${pi}" velocity="3.2" />
        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
        <dynamics damping="0.0" friction="0.0" />
    </joint>
    <link name="wrist_1_linka">
        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
        <inertial>
            <mass value="1.219" />
            <origin rpy="0 0 0" xyz="0.0 0.0 0.0" />
            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
        </inertial>
    </link>
    <joint name="wrist_1_joint_F" type="fixed">
        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
        <parent link="wrist_1_linka" />
        <child link="wrist_1_link" />
        <origin rpy="${alpha_4} 0.0 0.0" xyz="${ur5_a4} 0.0 0.0" />
    </joint>
    <link name="wrist_1_link">
        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
        <inertial>
            <origin xyz="0 0 0" rpy="0 0 0" />
            <mass value="1" />
            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
        </inertial>
    </link>
    <joint name="wrist_2_joint" type="revolute">
        <parent link="wrist_1_link" />
        <child link="wrist_2_linka" />
        <origin rpy="0.0 0.0 ${theta_5}" xyz="0.0 0.0 ${ur5_d5}" />
        <axis xyz="0 0 1" />
        <limit effort="28.0" lower="-${pi}" upper="${pi}" velocity="3.15" />
        <dynamics damping="0.0" friction="0.0" />
    </joint>
    <link name="wrist_2_linka">
        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
        <inertial>
            <origin xyz="0 0 0" rpy="0 0 0" />
            <mass value="1" />
            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
        </inertial>
    </link>
    <joint name="wrist_2_joint_F" type="fixed">
        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

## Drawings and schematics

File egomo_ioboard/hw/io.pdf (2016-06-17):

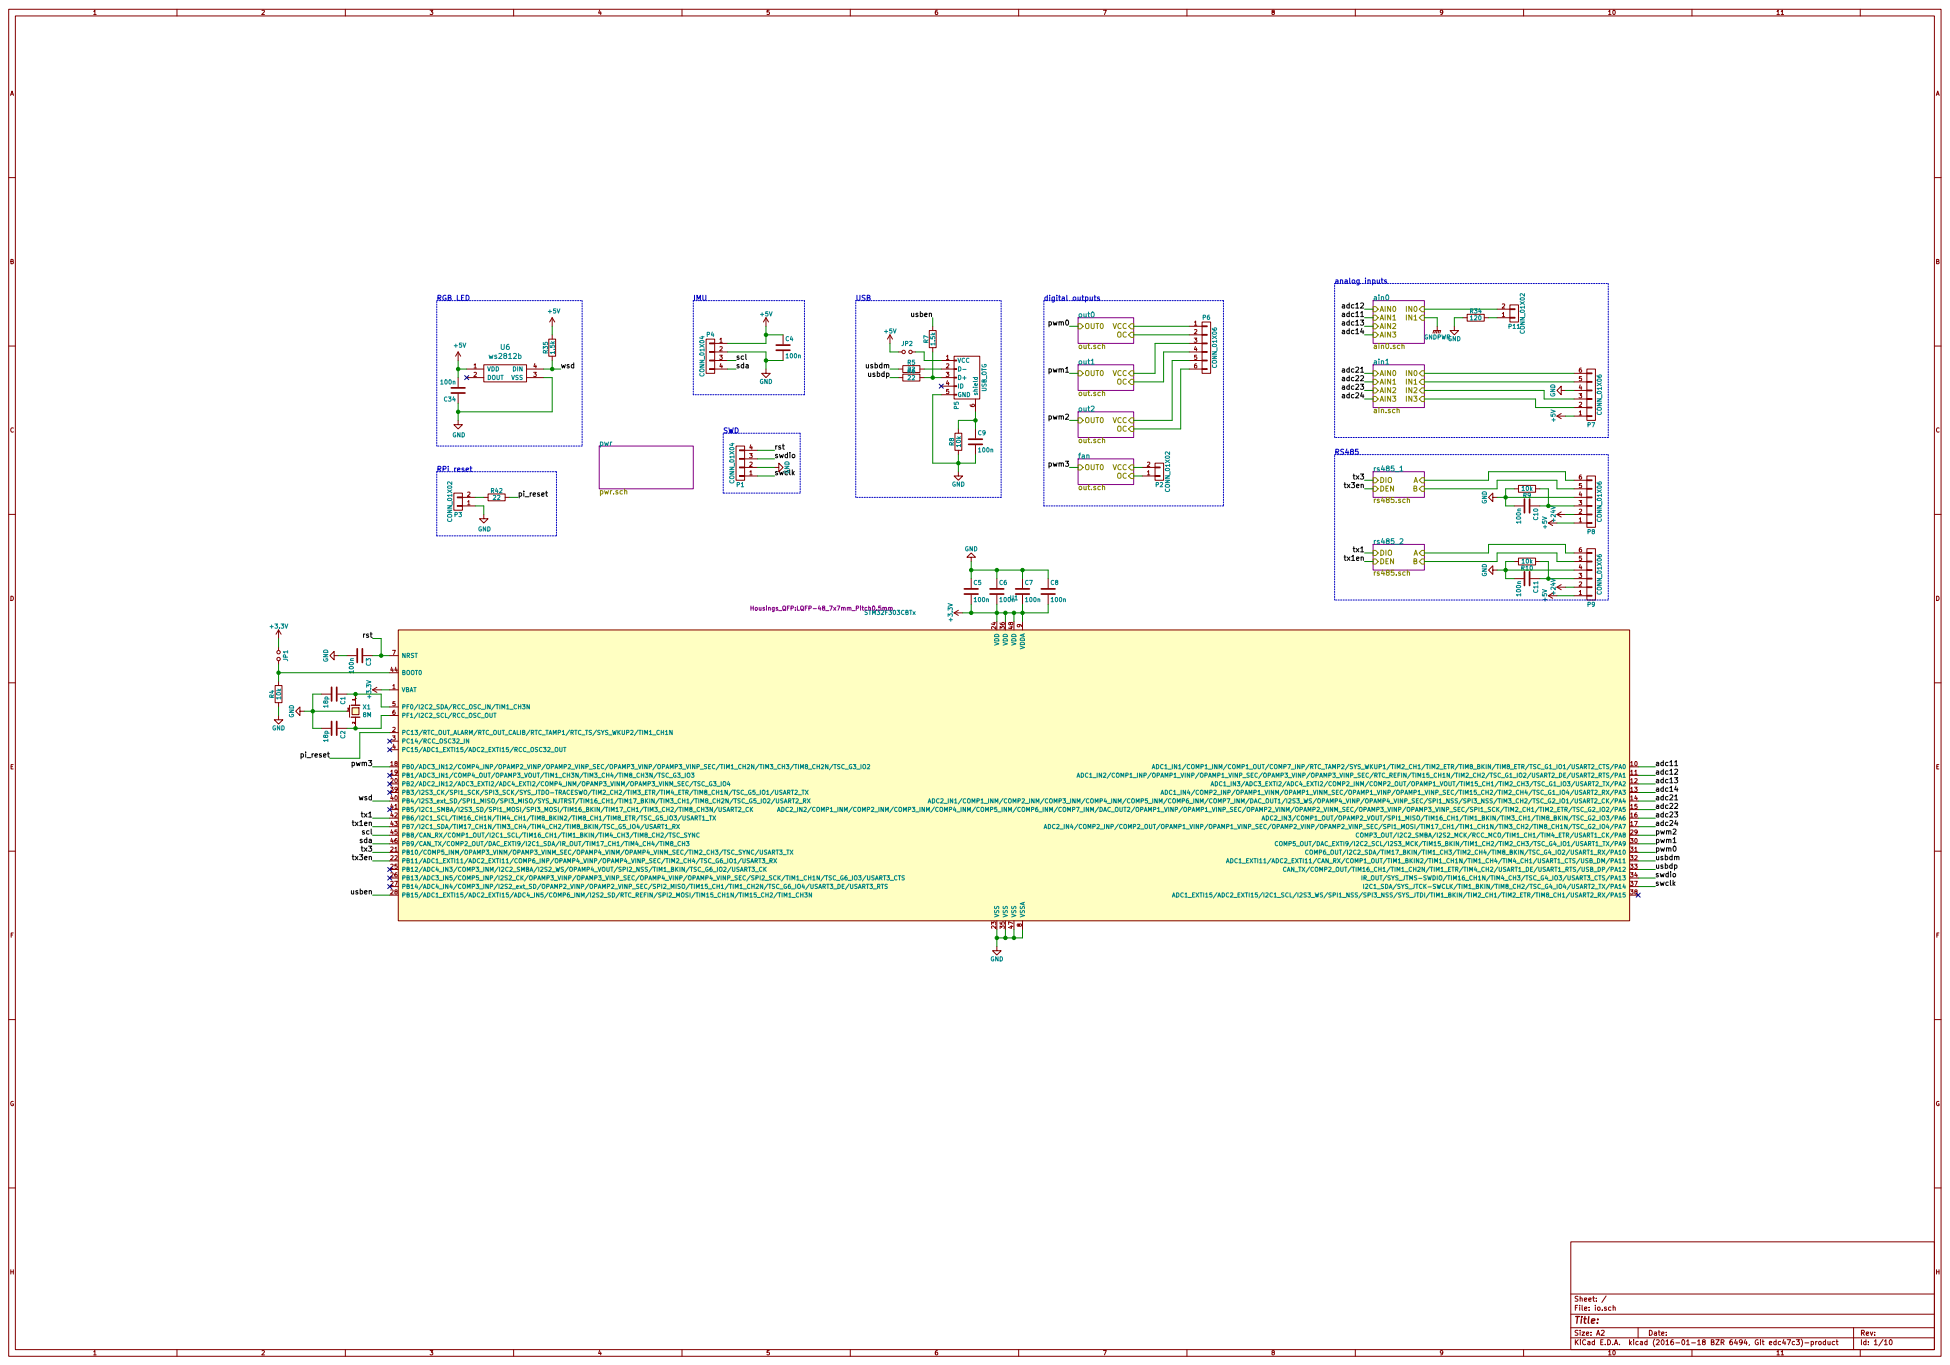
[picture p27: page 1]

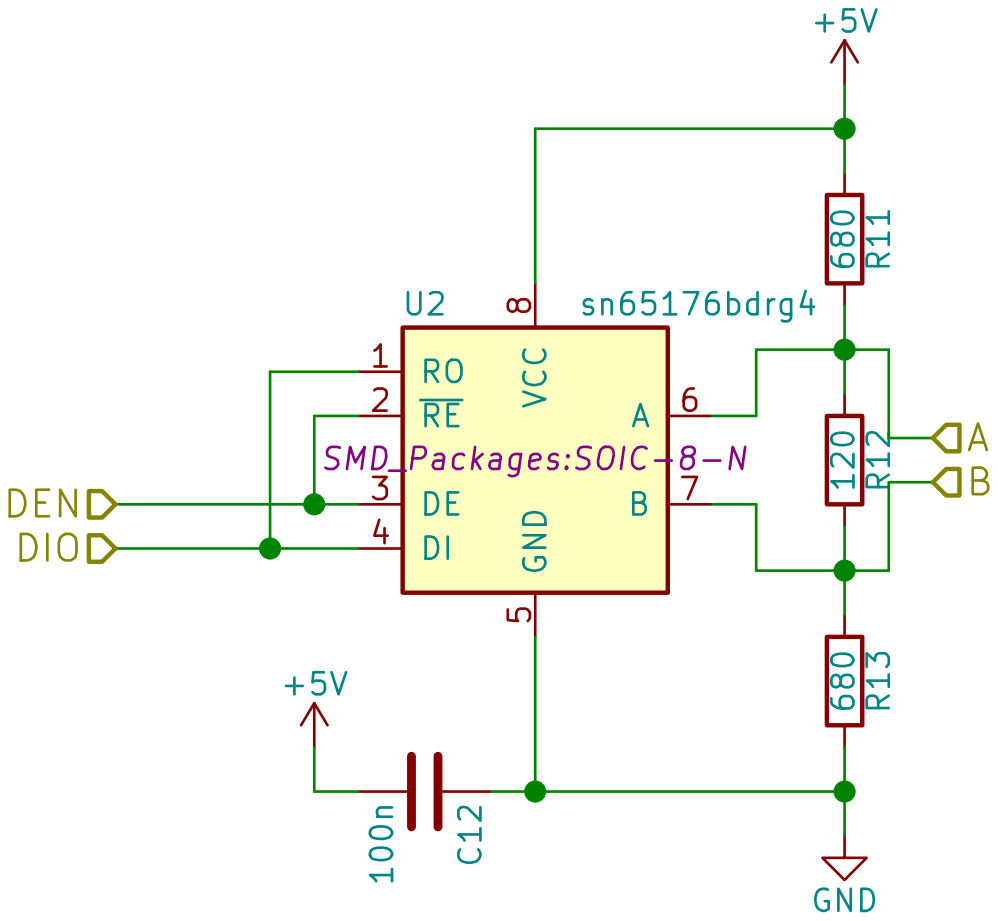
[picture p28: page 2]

Id: 2/10 Title: File: rs485.sch Sheet: /rs485_1/

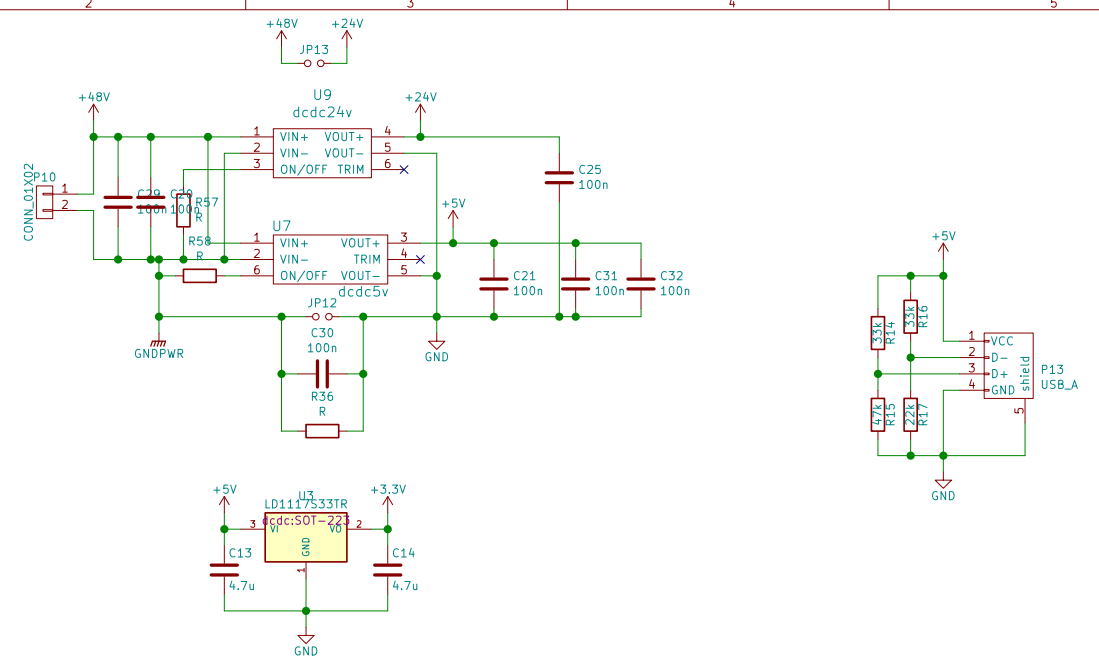
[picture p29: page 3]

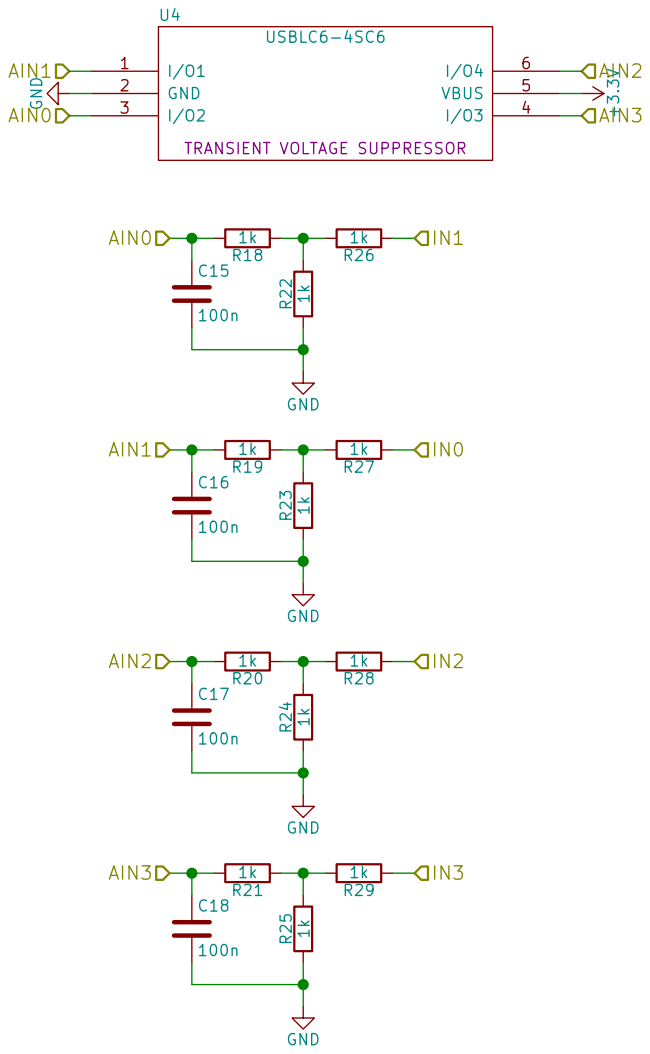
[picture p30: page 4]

Id: 4/10 Title: File: ain.sch Sheet: /ain1/

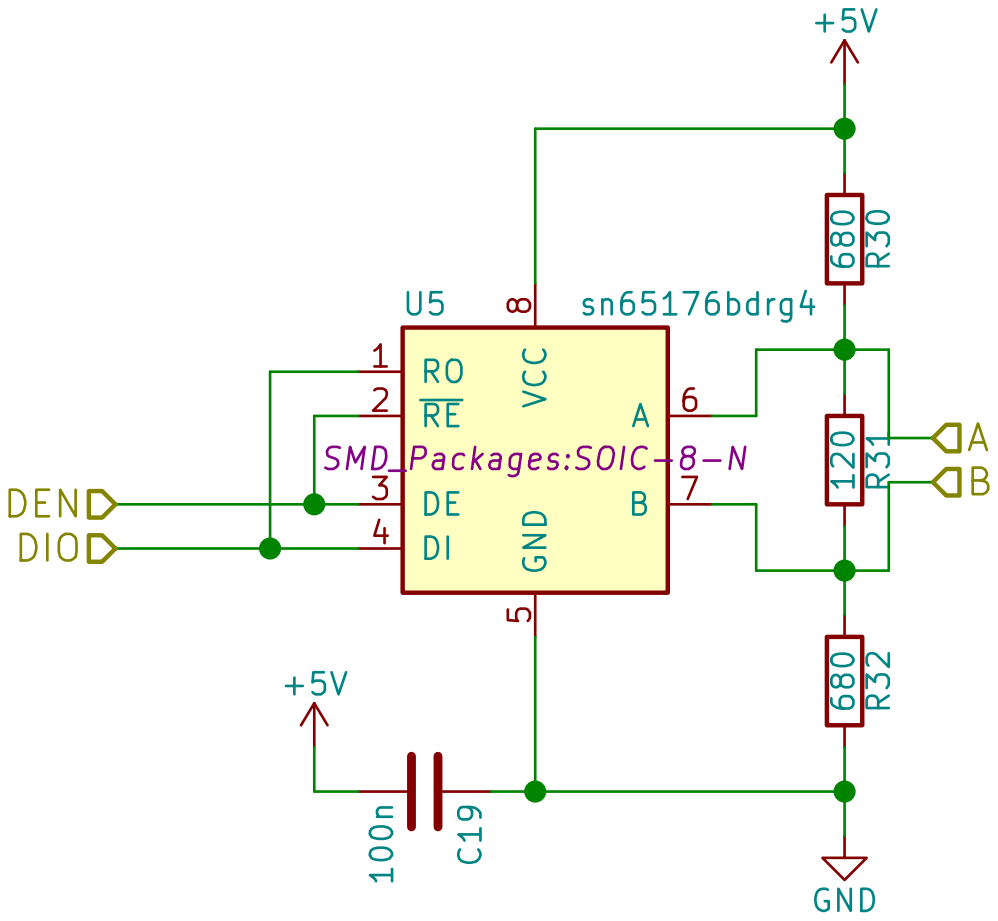
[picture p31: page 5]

Id: 5/10 Title: File: rs485.sch Sheet: /rs485_2/

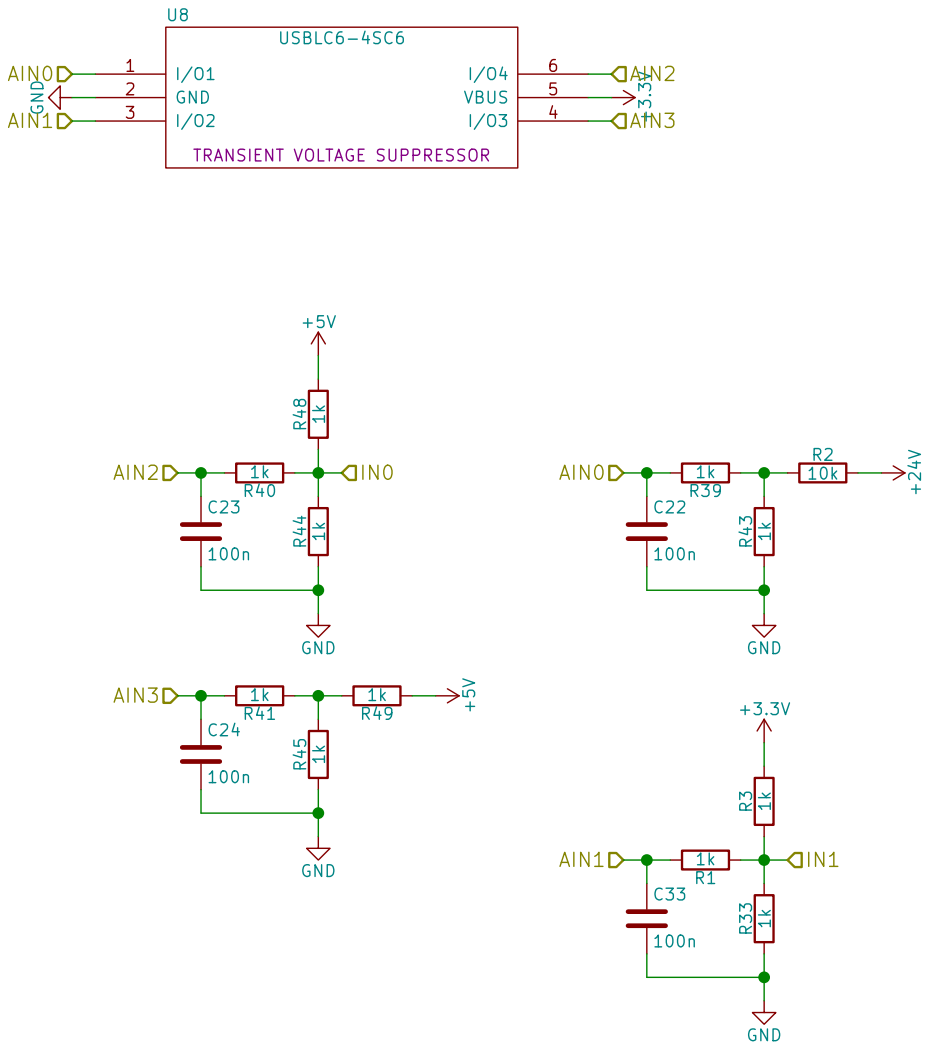
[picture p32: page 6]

Id: 6/10 Title: File: ain0.sch Sheet: /ain0/

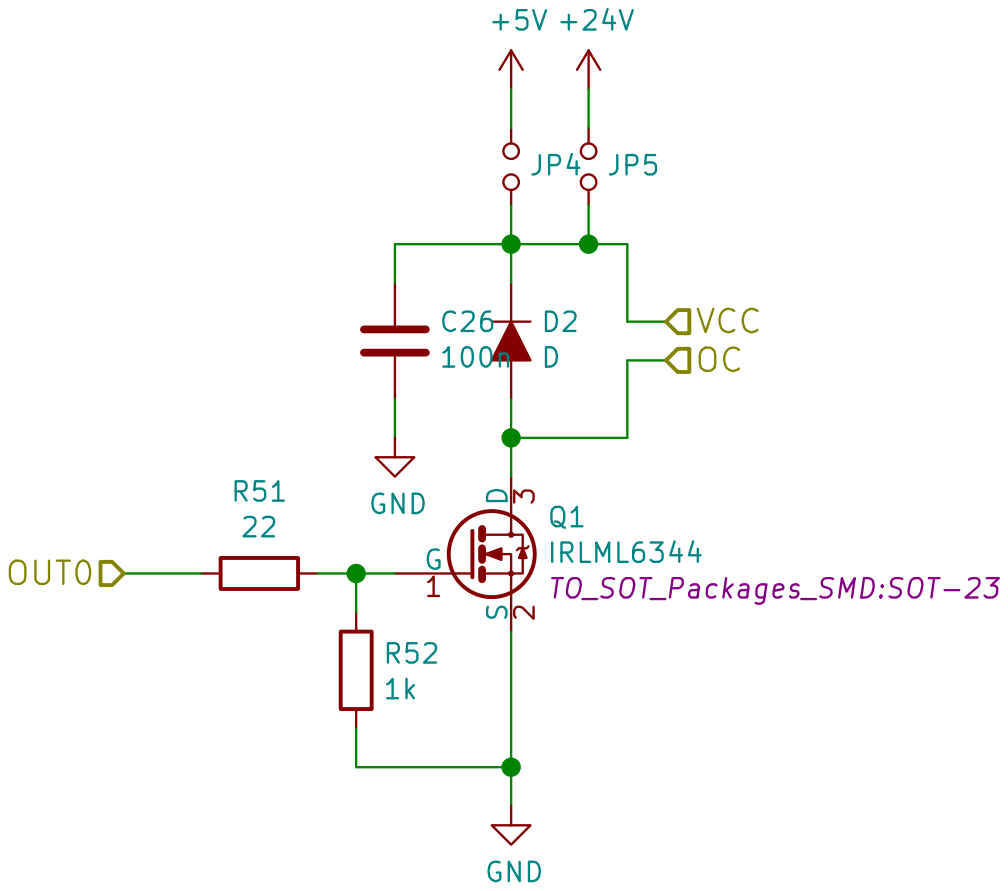
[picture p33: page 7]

Id: 7/10 Title: File: out.sch Sheet: /out0/ G

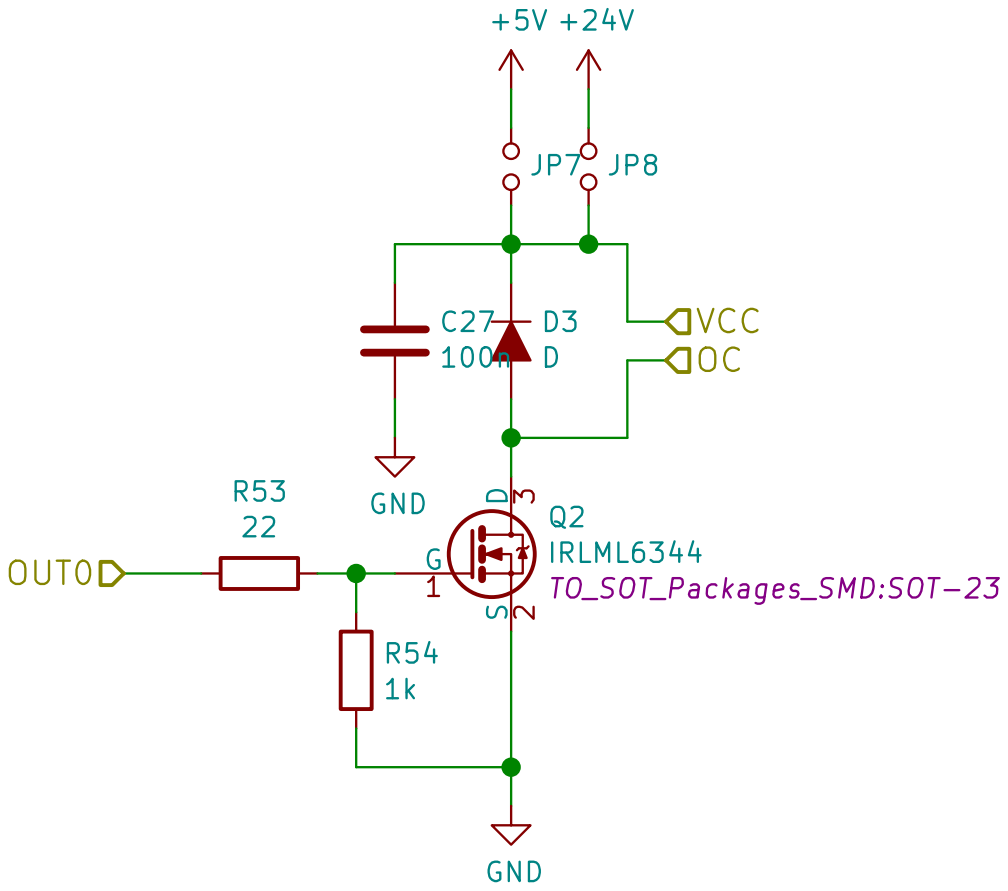
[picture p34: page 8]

Id: 8/10 Title: File: out.sch Sheet: /out1/ G

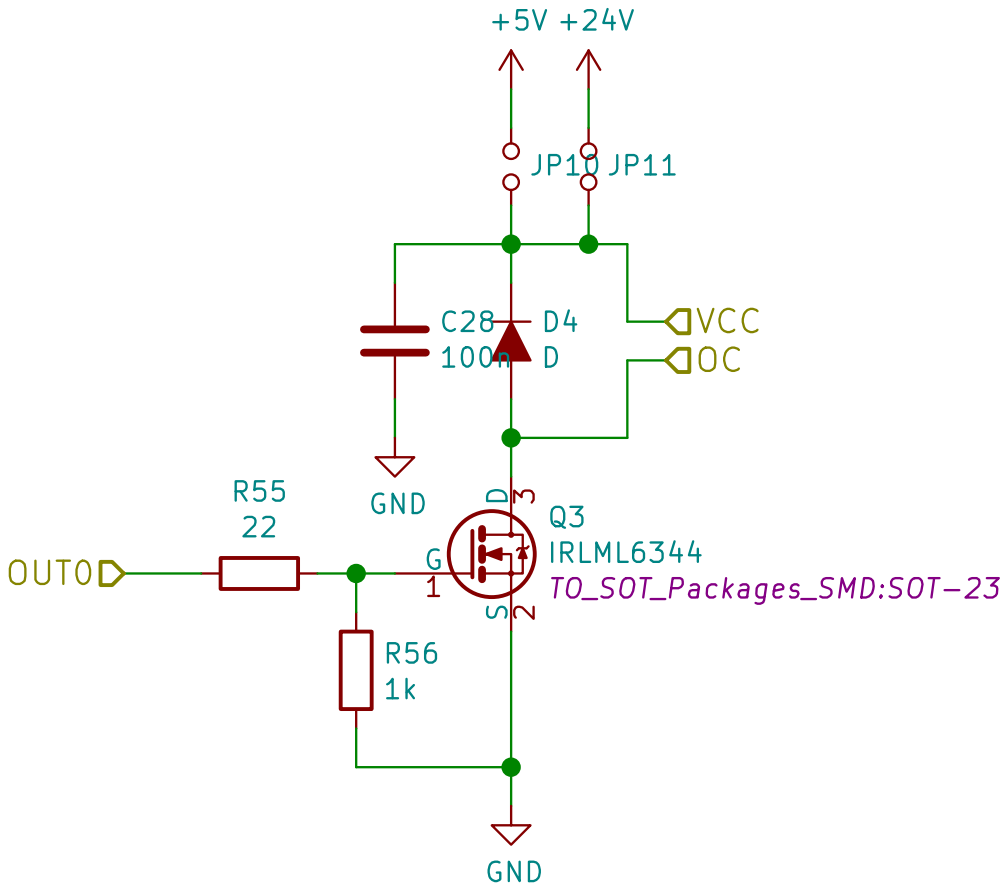
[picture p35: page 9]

Id: 9/10 Title: File: out.sch Sheet: /out2/ G

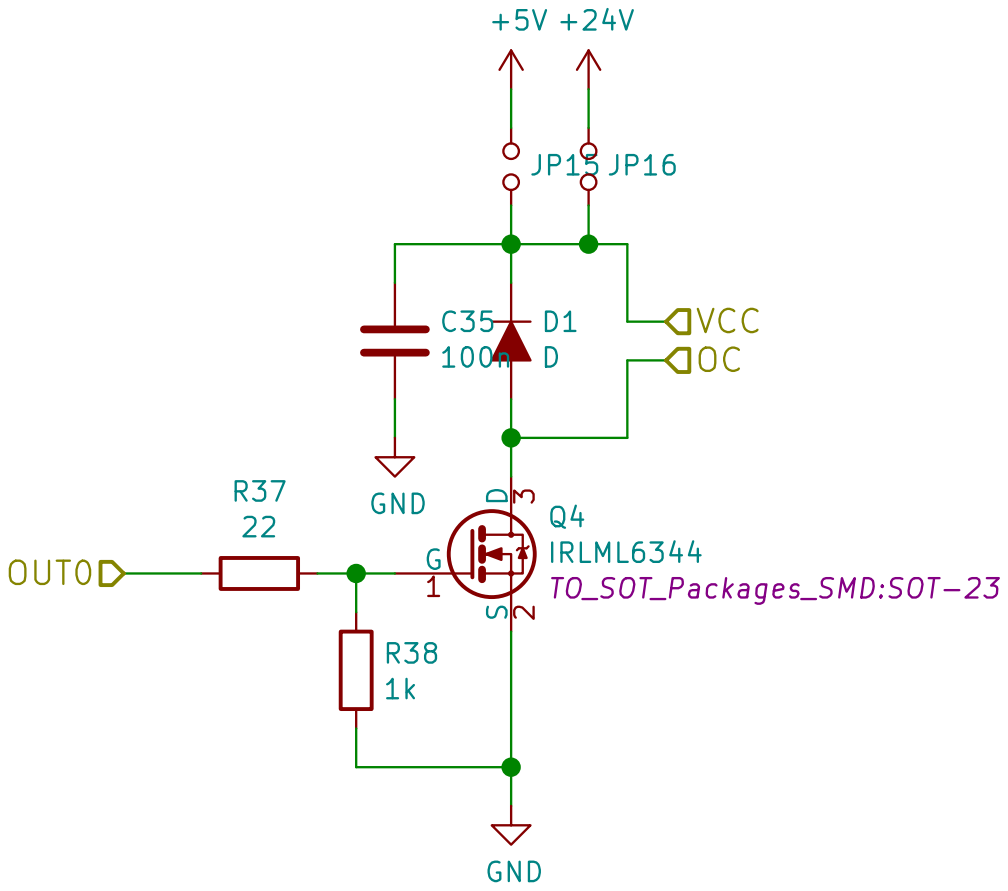
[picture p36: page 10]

Id: 10/10 Title: File: out.sch Sheet: /fan/ G

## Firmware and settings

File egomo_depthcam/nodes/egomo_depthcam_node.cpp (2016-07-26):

#include <ros/ros.h>
#include <ros/master.h>
#include <ros/callback_queue.h>
#include <ros/console.h>
#include <sensor_msgs/fill_image.h>
#include <sensor_msgs/CompressedImage.h>
#include <image_transport/image_transport.h>
#include <camera_info_manager/camera_info_manager.h>
#include <sstream>
#include <fstream>
#include <std_srvs/Empty.h>
#include <string>
#include <vector>
#include <stdint.h>
#include <sys/time.h>

#include <OpenNI.h>

#include "egomo_depthcam/DepthImage.h"
#include "egomo_depthcam/GetNewImage.h"
#include "egomo_depthcam/SetParameters.h"
#include "egomo_depthcam_node.h"
#include "egomo_depthcam/openni2_device.h"

#include <sys/time.h>
#include <unistd.h>

#include <boost/thread/thread.hpp>

#include <png.h>  // png compression
#include "lz4.h"  // LZ4 data compression library


using namespace egomo_depthcam;


OpenNI2CamNode::OpenNI2CamNode() :
                 nodeHandle("~"),
                 seqNum(0),
		 depthStreamSeqNum(0),
                 nSubscribers(0),
		 bitReorderBuffer(NULL),
		 bitReorderBufferSize(0),
		 lz4ResultBuffer(NULL),
		 lz4ResultBufferSize(0),
                 useLZ4compression(false)
{
  clock_gettime(CLOCK_MONOTONIC, &nodeStartTime);

  int depthWidthStill;
  int depthHeightStill;
  int depthWidthStream;
  int depthHeightStream;
  int irWidthStill;
  int irHeightStill;
  int irWidthStream;
  int irHeightStream;
  int frameRate;

  nodeHandle.param("depthimage_width_still", depthWidthStill, 640);
  nodeHandle.param("depthimage_height_still", depthHeightStill, 480);
  nodeHandle.param("depthimage_width_stream", depthWidthStream, 640);
  nodeHandle.param("depthimage_height_stream", depthHeightStream, 480);
  nodeHandle.param("irimage_width_still", irWidthStill, 640);
  nodeHandle.param("irimage_height_still", irHeightStill, 480);
  nodeHandle.param("irimage_width_stream", irWidthStream, 640);
  nodeHandle.param("irimage_height_stream", irHeightStream, 480);
  nodeHandle.param("frame_rate", frameRate, 30);
  nodeHandle.param("use_lz4compress", useLZ4compression, false);

  device.SetResolution(OpenNI2Device::kDepthStill, depthWidthStill, depthHeightStill);
  device.SetResolution(OpenNI2Device::kDepthStream, depthWidthStream, depthHeightStream);
  device.SetResolution(OpenNI2Device::kIRstill, irWidthStill, irHeightStill);
  device.SetResolution(OpenNI2Device::kIRstream, irWidthStream, irHeightStream);
  int newFrameRate=device.SetFrameRate(frameRate);
  if(newFrameRate!=frameRate) {
    ROS_WARN("Requested frame rate of %i fps not supported. Set to %i fps.", frameRate, newFrameRate);
  }

  AdvertiseService();
}

OpenNI2CamNode::~OpenNI2CamNode() {

}


void OpenNI2CamNode::AdvertiseService()
{
  std::cout << "Advertising egomo depthcam service..." << std::endl;
  serverGetNewImage = nodeHandle.advertiseService("get_new_image",
						  &OpenNI2CamNode::RecordSendImage, this);
  serverSetParameters = nodeHandle.advertiseService("set_parameters",
						  &OpenNI2CamNode::SetParameters, this);

  boost::lock_guard<boost::mutex> lock(connectionMutex);
  ros::SubscriberStatusCallback subscriberCb = boost::bind(&OpenNI2CamNode::ConnectDepthCb, this);
  serverDepthStream = nodeHandle.advertise<egomo_depthcam::DepthImage>("depthstream/image", 1, subscriberCb, subscriberCb);
  device.RegisterDepthFrameCallback(boost::bind(&OpenNI2CamNode::NewDepthImgCallback, this, _1, _2));
}


bool OpenNI2CamNode::NewDepthImgCallback(openni::VideoFrameRef &currFrame, struct timeval timestamp)
{
  timespec timeCbStart, timeCbEnd;  // debug: time the whole callback routine
  clock_gettime(CLOCK_MONOTONIC, &timeCbStart);


  depthStreamSeqNum++;

  // timespec timeCurr;
  // if(callbackCounter==0)
  //   clock_gettime(CLOCK_MONOTONIC, &timerFramerate);
  // if(callbackCounter>10) {
  //   clock_gettime(CLOCK_MONOTONIC, &timeCurr);
  //   std::cout << "10 callbacks took " << device.CalcTimeDiff(timerFramerate, timeCurr) << " ms" << std::endl;
  //   callbackCounter=0;
  //   clock_gettime(CLOCK_MONOTONIC, &timerFramerate);
  // }

  depthStreamImg.header.stamp = ros::Time::now();
  depthStreamImg.header.seq = depthStreamSeqNum;
  depthStreamImg.header.frame_id = "";

  depthStreamImg.height = (unsigned int) currFrame.getHeight();
  depthStreamImg.width = (unsigned int) currFrame.getWidth();

  depthStreamImg.is_bigendian=false;
  depthStreamImg.step=currFrame.getStrideInBytes();
  depthStreamImg.data_size_uncompressed = currFrame.getDataSize();

  if(useLZ4compression) {
    if(bitReorderBufferSize != currFrame.getDataSize()) {
      //std::cout << "Realloc bit reorder buffer size" << std::endl;
      delete[] bitReorderBuffer;
      delete[] lz4ResultBuffer;

      bitReorderBufferSize=currFrame.getDataSize();
      bitReorderBuffer = new char[bitReorderBufferSize];

      lz4ResultBufferSize = bitReorderBufferSize + 0.1*bitReorderBufferSize;  // add some reserve in case of incompressible data
      lz4ResultBuffer = new char[bitReorderBufferSize];

      //std::cout << "New sizes: bitReorderBufferSize=" << bitReorderBufferSize << ", lz4ResultBufferSize=" << lz4ResultBufferSize << std::endl;
    }


    timespec timeStart, timeEnd;  // debug: time the main compression routine
    clock_gettime(CLOCK_MONOTONIC, &timeStart);
    ReorderBits((char*)currFrame.getData(), currFrame.getDataSize(), bitReorderBuffer, bitReorderBufferSize);
    clock_gettime(CLOCK_MONOTONIC, &timeEnd);
    // std::cout<< "Bit reorder time: " << device.CalcTimeDiff(timeStart, timeEnd) << " ms" << std::endl;

    clock_gettime(CLOCK_MONOTONIC, &timeStart);
    depthStreamImg.data_size=CompressLZ4(bitReorderBuffer,  depthStreamImg.data_size_uncompressed, lz4ResultBuffer);
    clock_gettime(CLOCK_MONOTONIC, &timeEnd);
    // std::cout<< "LZ4 compression time: " << device.CalcTimeDiff(timeStart, timeEnd) << " ms" << std::endl;

    depthStreamImg.data.resize(depthStreamImg.data_size);
    memcpy(&depthStreamImg.data[0], lz4ResultBuffer, depthStreamImg.data_size);
    depthStreamImg.compressionType="lz4";
  }
  else {
    depthStreamImg.data_size = depthStreamImg.data_size_uncompressed;
    depthStreamImg.data.resize(depthStreamImg.data_size);
    memcpy(&depthStreamImg.data[0], (char*)currFrame.getData(), currFrame.getDataSize());

    depthStreamImg.compressionType="none";
  }

  struct timeval tp;
  gettimeofday(&tp, NULL);
  depthStreamImg.timeSend_sec = tp.tv_sec;
  depthStreamImg.timeSend_usec = tp.tv_usec;

  serverDepthStream.publish(depthStreamImg);

  callbackCounter++;
  clock_gettime(CLOCK_MONOTONIC, &timeCbEnd);
  // std::cout<< "Overall Cb time: " << device.CalcTimeDiff(timeCbStart, timeCbEnd) << " ms" << std::endl;
  return true;
}

void OpenNI2CamNode::ConnectDepthCb()
{
  boost::lock_guard<boost::mutex> lock(connectionMutex);
  nSubscribers = serverDepthStream.getNumSubscribers(); // update the number of connected clients
  // std::cout << "number of connected clients: " << nSubscribers << std::endl;

  if(nSubscribers>0) {
    device.StartDepthStream();
  }
  else {
    device.StopDepthStream();
  }
  // optional: do something if someone connects or nSubscribers==0 (=noone connected)
}


bool OpenNI2CamNode::RecordSendImage(egomo_depthcam::GetNewImageRequest& req, egomo_depthcam::GetNewImageResponse& res)
{
  timespec timeTotalStart, timeTotalEnd;
  clock_gettime(CLOCK_MONOTONIC, &timeTotalStart);

  OpenNI2Device::ImageType imgType = (OpenNI2Device::ImageType)req.imgType;
  const openni::VideoFrameRef *imgData;
  timespec timeStart, timeEnd;

  // std::cout << "-------------- Capturing image type " << imgType << std::endl;

  clock_gettime(CLOCK_MONOTONIC, &timeStart);
  imgData = device.GetSingleImage(imgType);
  clock_gettime(CLOCK_MONOTONIC, &timeEnd);
  // std::cout<< "Overall img capture time: " << device.CalcTimeDiff(timeStart, timeEnd) << " ms" << std::endl;
  if(imgData==NULL)  // some error occured and we don't have a valid image
    return false;

  res.img.header.stamp = ros::Time::now();
  res.img.header.seq = seqNum;
  seqNum++;
  res.img.header.frame_id = "";

  res.img.height = (unsigned int) imgData->getHeight();
  res.img.width = (unsigned int) imgData->getWidth();

  res.img.encoding = "";
  res.img.is_bigendian=false;
  res.img.step=imgData->getStrideInBytes();

  size_t st0 = (imgData->getDataSize());
  res.img.data.resize(st0);

  memcpy(&res.img.data[0], imgData->getData(), st0);

  clock_gettime(CLOCK_MONOTONIC, &timeTotalEnd);
  // std::cout << "OpenNI2CamNode::RecordSendImage total time " << device.CalcTimeDiff(timeTotalStart, timeTotalEnd) << " ms" << std::endl;
  return true;
}


// Dynamic reconfiguration is currently not supported
bool OpenNI2CamNode::SetParameters(egomo_depthcam::SetParametersRequest& req, egomo_depthcam::SetParametersResponse& res)
{
  // // std::cout << "This is SetParamters" << std::endl;

  // timespec timeTotalStart, timeTotalEnd;
  // clock_gettime(CLOCK_MONOTONIC, &timeTotalStart);

  // int imgWidth = req.imgWidth;
  // int imgHeight = req.imgHeight;
  // int camStream = req.camStream;
  // int irProjectorStatus = req.irProjector;

  // if(irProjectorStatus<0) {
  //   res.success=device.SetResolution(camStream, imgWidth, imgHeight);
  //   clock_gettime(CLOCK_MONOTONIC, &timeTotalEnd);
  //   std::cout << "Switching resolution took " << device.CalcTimeDiff(timeTotalStart, timeTotalEnd) << " ms" << std::endl;
  // }
  // else if(irProjectorStatus>=0 && camStream<0) {
  //   if(irProjectorStatus==0)
  //     device.StopDepthStream();
  //   else
  //     device.StartDepthStream();
  // }

  return true;
}


void OpenNI2CamNode::TryReconnect()
{
  nodeHandle.shutdown(); // Shutdown every handle created through the NodeHandle.
  std::cout << "Connection to master lost. Trying to reconnect ..." << std::endl;
  do {
    usleep(1*1000*1000); // sleep for one second
  } while(ros::master::check() == false);

  std::cout << "Connection re-established." << std::endl;
  AdvertiseService();
}


int main(int argc, char **argv) {
  ros::init(argc, argv, "egomo_depthcam");
  egomo_depthcam::OpenNI2CamNode a;
  static const float loopFreq=60;
  static const float freqCheckROScore=2; // check connection to master with 2 Hz

  float counter=0;
  while (ros::ok()) {
    if(counter > loopFreq/freqCheckROScore) {
      counter=0;
      if(ros::master::check() == false) {
        a.TryReconnect();
      }
    }
    counter++;

    // from documentation:
    // Parameters for callAvailable:
    //  timeout     The amount of time to wait for at least one callback to be available.
    //              If there is already at least one callback available, this parameter does nothing.
    ros::getGlobalCallbackQueue()->callAvailable(ros::WallDuration(1.0/loopFreq));
  }
  return EXIT_SUCCESS;
}


// Reorders the bits within the depth image so that the LZ4 algorithm can achive better compression performance
char *OpenNI2CamNode::ReorderBits(const char *inData, int lengthByte, char *out, int outLenghtBytes)
{
  if(out==NULL) {
    if(lengthByte%16 == 0)
      outLenghtBytes=lengthByte;
    else
      outLenghtBytes = ((lengthByte/16)+1)*16;

    out = new char[outLenghtBytes];
  }

  int nPixel=lengthByte/2;
  int stride=lengthByte/16;
  for(int i=0; i<lengthByte; i++)
    out[i]=0;

  int buffer[16];
  for(int i=0; i<16; i++)
    buffer[i]=0;
  long outPos=0;
  int bitpos=0;

  const unsigned short *in=reinterpret_cast<const unsigned short*>(inData);

  for(int i=0; i<nPixel; i++) {
    if(bitpos>=8) {
      for(int j=0; j<16; j++) {
   	//std::cout << "loop " << outPos << ", j=" << j << ": " << std::bitset<8>(buffer[j]) << std::endl;
   	out[j*stride + outPos] = buffer[j];
   	buffer[j]=0;
      }
      outPos++;
      bitpos=0;
    }

    for(int j=0; j<16; j++) {
      buffer[15-j] |= ((in[i] >> j) & 1) << (7-bitpos);
    }

    bitpos++;
  }

  for(int j=0; j<16; j++)
     out[long(j*stride) + outPos] = buffer[j];

  return out;
}


int OpenNI2CamNode::CompressLZ4(char *inputBuffer, int inputSize, char *outputBuffer)
{
  static const int BLOCK_BYTES = 1024 * 8;

  LZ4_stream_t lz4Stream_body;
  LZ4_stream_t* lz4Stream = &lz4Stream_body;

  int inpos=0;
  int outpos=0;
  LZ4_resetStream(lz4Stream);

  int cmpBytes=0;
  while(inputSize>0) {
    int inpBytes;
    if(inputSize>=BLOCK_BYTES)
      inpBytes=BLOCK_BYTES;
    else
      inpBytes=inputSize;

    char cmpBuf[LZ4_COMPRESSBOUND(BLOCK_BYTES)];
    cmpBytes = LZ4_compress_fast_continue(lz4Stream, &inputBuffer[inpos], cmpBuf, inpBytes, sizeof(cmpBuf), 1);
    if(cmpBytes <= 0) {
      std::cout << "Error in compression function" << std::endl;
      break;
    }

    std::memcpy(&outputBuffer[outpos], reinterpret_cast<char *>(&cmpBytes), sizeof(cmpBytes));
    outpos+=sizeof(cmpBytes);
    std::memcpy(&outputBuffer[outpos], cmpBuf, (size_t) cmpBytes);
    outpos+=cmpBytes;
    inpos += inpBytes;
    inputSize -= inpBytes;
  }

  // add a next-block-size = 0 information to indicate end of compressed data
  cmpBytes=0;
  std::memcpy(&outputBuffer[outpos], reinterpret_cast<char *>(&cmpBytes), sizeof(cmpBytes));
  outpos+=sizeof(cmpBytes);

  return outpos;
}



// Convert the raw data contained in VideoFrameRef to an PNG image stored in imgCompressed
// PNG parameters like compression factor, etc. are hard-coded at the moment
// For the raspberry, the PNG compression requires to much time so currently a LZ4 with "manual" bit
// reordering is used.
bool OpenNI2CamNode::CompressPNG(const openni::VideoFrameRef *imgData, std::vector<unsigned char> &imgCompressed)
{
 // convert the image to png format
  // TODO: check if memory allocation/de-allocation can be optimized

  int imgHeight = imgData->getHeight();
  int imgWidth = imgData->getWidth();
  int imgStrideInBytes = imgData->getStrideInBytes();
  const unsigned char *inputData = (const unsigned char *)imgData->getData();

  // data structure which will hold the compressed image
  struct pngMemEncode pngBuffer;
  pngBuffer.buffer=NULL;
  pngBuffer.size=0;

  png_structp png_ptr = png_create_write_struct(PNG_LIBPNG_VER_STRING, NULL, NULL, NULL);
  if (!png_ptr)
    return false;
  png_infop info_ptr = png_create_info_struct(png_ptr);
  if (!info_ptr) {
    png_destroy_write_struct(&png_ptr, (png_infopp)NULL);
    return false;
  }
  if (setjmp(png_jmpbuf(png_ptr))) {  // c style error handling
    png_destroy_write_struct(&png_ptr, &info_ptr);
    return false;
  }
  // register callback functions to write the compressed data to memory instead of disk file
  png_set_write_fn(png_ptr, &pngBuffer, LocalPNGWriteData, LocalPNGFlush);

  // set img properties: width, height,
  //                     bit_depth, color_type, interlace_type,
  //                     compression_type, filter_method
  png_set_IHDR(png_ptr, info_ptr, imgWidth, imgHeight,
	       16, PNG_COLOR_TYPE_GRAY, PNG_INTERLACE_NONE,
	       PNG_COMPRESSION_TYPE_DEFAULT, PNG_FILTER_TYPE_DEFAULT);
  png_set_compression_level( png_ptr, 2);  // png compression level 2: compromise of file size and compression speed
  // write the png header data
  png_write_info(png_ptr, info_ptr);

  // perform the actual compression
  png_bytepp rowPointers = (png_bytepp)png_malloc(png_ptr, imgHeight * sizeof(png_bytep));
  for(int y=0; y<imgHeight; y++)
    rowPointers[y] = (png_bytep)(&inputData[y*imgData->getStrideInBytes()]);


  //timespec timeStart, timeEnd;  // debug: time the main png compression routine
  //clock_gettime(CLOCK_MONOTONIC, &timeStart);

  png_write_image(png_ptr, rowPointers);

  //clock_gettime(CLOCK_MONOTONIC, &timeEnd);
  //std::cout << "core of png compression took " << device.CalcTimeDiff(timeStart, timeEnd) << " ms" << std::endl;


  png_write_end(png_ptr, NULL);

  // at this point pngBuffer.buffer contains the PNG image of size pngBuffer.size bytes
  std::cout << "png compressed size: " << pngBuffer.size << std::endl;

  // debug: dump resulting png and the raw data to files
  // std::ofstream bStream("test_my.png", std::fstream::out | std::fstream::binary);
  // if (bStream) {
  //   bStream.write(pngBuffer.buffer, pngBuffer.size);
  //   std::cout << "bstream status: " << bStream.good() << std::endl;
  // }
  // std::ofstream bStreamB("test_my.bin", std::fstream::out | std::fstream::binary);
  // if (bStreamB) {
  //   bStreamB.write(((char *)imgData->getData()), imgData->getDataSize());
  //   std::cout << "bstreamB status: " << bStreamB.good() << std::endl;
  // }

  //size_t st0 = (imgData->getDataSize());
  imgCompressed.resize(pngBuffer.size);
  memcpy(&imgCompressed[0], pngBuffer.buffer, pngBuffer.size);

  // delete the rowPointers array
  png_free(png_ptr, rowPointers);
  // cleanup: delete the internal data structues
  png_destroy_write_struct(&png_ptr, &info_ptr);

  return true;
}



// Utility function for CompressPNG, don't call it from elsewhere
void OpenNI2CamNode::LocalPNGWriteData(png_structp png_ptr, png_bytep data, png_size_t length)
{
  // with libpng15 next line causes pointer deference error; use libpng12
  struct pngMemEncode* p=(struct pngMemEncode*)png_get_io_ptr(png_ptr); // was png_ptr->io_ptr
  size_t nsize = p->size + length;

  // allocate or grow buffer
  if(p->buffer)
    p->buffer = (char*) realloc(p->buffer, nsize);
  else
    p->buffer = (char*) malloc(nsize);

  if(!p->buffer)
    png_error(png_ptr, "Write Error");

  /* copy new bytes to end of buffer */
  memcpy(p->buffer + p->size, data, length);
  p->size += length;
}


// This is optional but included to show how png_set_write_fn() is called
void OpenNI2CamNode::LocalPNGFlush(png_structp png_ptr)
{
  return;
}


long OpenNI2CamNode::TimeDiffSinceStart(timespec compareTime)
{
  long timediff = ( compareTime.tv_sec - (nodeStartTime.tv_sec+1))*1000*1000; // to get microseconds
  timediff += (compareTime.tv_nsec + ((1000*1000*1000) - nodeStartTime.tv_nsec)) / 1000;

  return timediff;
}

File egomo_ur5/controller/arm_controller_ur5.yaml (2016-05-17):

   # Settings for ros_control control loop
hardware_control_loop:
   loop_hz: 125

# Settings for ros_control hardware interface
hardware_interface:
   joints:
     - shoulder_pan_joint
     - shoulder_lift_joint
     - elbow_joint
     - wrist_1_joint
     - wrist_2_joint
     - wrist_3_joint

# Publish all joint states ----------------------------------
joint_state_controller:
   type:         joint_state_controller/JointStateController
   publish_rate: 125

# Publish wrench ----------------------------------
force_torque_sensor_controller:
   type:         force_torque_sensor_controller/ForceTorqueSensorController
   publish_rate: 125

# Joint Trajectory Controller - position based -------------------------------
# For detailed explanations of parameter see http://wiki.ros.org/joint_trajectory_controller
pos_based_pos_traj_controller:
   type: position_controllers/JointTrajectoryController
   joints:
     - shoulder_pan_joint
     - shoulder_lift_joint
     - elbow_joint
     - wrist_1_joint
     - wrist_2_joint
     - wrist_3_joint
   constraints:
     goal_time: 0.6
     stopped_velocity_tolerance: 0.05
     shoulder_pan_joint: {trajectory: 0.1, goal: 0.1}
     shoulder_lift_joint: {trajectory: 0.1, goal: 0.1}
     elbow_joint: {trajectory: 0.1, goal: 0.1}
     wrist_1_joint: {trajectory: 0.1, goal: 0.1}
     wrist_2_joint: {trajectory: 0.1, goal: 0.1}
     wrist_3_joint: {trajectory: 0.1, goal: 0.1}
   stop_trajectory_duration: 0.5
   state_publish_rate:  125
   action_monitor_rate: 10
   
# Joint Trajectory Controller - velocity based -------------------------------
# For detailed explanations of parameter see http://wiki.ros.org/joint_trajectory_controller
vel_based_pos_traj_controller:
   type: velocity_controllers/JointTrajectoryController
   joints:
     - shoulder_pan_joint
     - shoulder_lift_joint
     - elbow_joint
     - wrist_1_joint
     - wrist_2_joint
     - wrist_3_joint
   constraints:
      goal_time: 0.6
      stopped_velocity_tolerance: 0.05
      shoulder_pan_joint: {trajectory: 0.1, goal: 0.1}
      shoulder_lift_joint: {trajectory: 0.1, goal: 0.1}
      elbow_joint: {trajectory: 0.1, goal: 0.1}
      wrist_1_joint: {trajectory: 0.1, goal: 0.1}
      wrist_2_joint: {trajectory: 0.1, goal: 0.1}
      wrist_3_joint: {trajectory: 0.1, goal: 0.1}
   stop_trajectory_duration: 0.5
   state_publish_rate:  125
   action_monitor_rate: 10
   gains:
      #!!These values are useable, but maybe not optimal
      shoulder_pan_joint: {p: 2.2,  i: 0.0, d: 0.01, i_clamp: 1}
      shoulder_lift_joint: {p: 2.2,  i: 0.0, d: 0.01, i_clamp: 1}
      elbow_joint: {p: 2.2,  i: 0.0, d: 0.01, i_clamp: 1}
      wrist_1_joint: {p: 2.2,  i: 0.0, d: 0.01, i_clamp: 1}
      wrist_2_joint: {p: 2.2,  i: 0.0, d: 0.01, i_clamp: 1}
      wrist_3_joint: {p: 2.2,  i: 0.0, d: 0.01, i_clamp: 1}

  



#gripper_controller:
#  type: position_controllers/JointTrajectoryController
#  joints:
#     - robotiq_85_finger_right_1_joint
#  constraints:
#      goal_time: 0.6
#      stopped_velocity_tolerance: 0.05
#      robotiq_85_left_knuckle_joint: {trajectory: 0.1, goal: 0.1}
#  stop_trajectory_duration: 0.5
#  state_publish_rate:  25
#  action_monitor_rate: 10

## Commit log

2016-03-25 Add simple robotiq-2-finger gripper URDF
    [gripper_base.stl, gripper_coupling.stl, gripper_finger_left_1.stl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]
2016-03-27 Add UR5+FT300+Egomo models
    [base.stl, egomo-1.stl, forearm.stl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]
2016-04-12 plugin for gazeboo. Controllers for joint control
    [common.gazebo.xacro]
2016-04-12 added new launch script for real robot. Testing with joint controllers
2016-04-13 controller definitions
    [arm_controller_ur5.yaml, cart_arm_controller_ur5.yaml, joint_state_controller.yaml]
2016-04-13 gazebo definition added to urdf ur5
    [ur5_egomo_table.urdf]
2016-04-13 first test with new controller
    [arm_controller_ur5.yaml, ur5_egomo_table.urdf]
2016-04-13 start of pos controller and vel controller is loaded.
    [arm_controller_ur5.yaml]
2016-04-18 changed controller + moveit configuration
    [arm_controller_ur5.yaml]
2016-04-20 Knoten, Messages, Services für Gripper/FT/IMU hinzugefügt. TODO: Cmake + Package modifizieren damit unterpakete gebaut werden
2016-04-21 necessary files for gazebo simulation
    [robotiq-2-finger-85.urdf.xacro, ur.gazebo.xacro, ur.transmission.xacro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]
2016-04-21 controller configuration
    [arm_controller_ur5.yaml]
2016-04-25 new folder strukture
    [arm_controller_ur5.yaml, base.stl, cart_arm_controller_ur5.yaml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]
2016-04-25 added xacro data and adapted descrintion for ros param server to use the new formed urdf
    [ur5_egomo_table.urdf.xacro]
2016-04-25 start to parameterize full dh parameters in urdf
    [ur5_egomo_table.urdf.xacro]
2016-04-28 Removed unnecessary flags for stty. Added alternative function for writing data in one block. Added if-statements to prevent unnecessary commands.
    [ros_egomo_node.lua]
2016-04-28 Small fix concerning variable visibility
    [ros_egomo_node.lua]
2016-05-02 Changed communication with the IO-Board to meet the new ascii process data protocol. Furthermore, preparation for publishing gripper joint state has been added. Due to compatibility the communication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
2016-05-02 Changed prints on reconnect
2016-05-04 added urdf example
    [arm_controller_ur5.yaml, cart_arm_controller_ur5.yaml, ur5_egomo_table.urdf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]
2016-05-04 latest changes
    [arm_controller_ur5.yaml]
2016-05-04 fixed new urdf file. TESTED WITH REAL ROBOT
    [ur5_egomo_table.urdf.xacro]
2016-05-12 Update collision meshes with narrow space
    [base.stl, egomo-1.stl, forearm.stl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]
2016-05-17 optimized configuration for controller since some parameters are not used
    [arm_controller_ur5.yaml]
2016-05-24 Minor changes for debugging joint states.
2016-06-01 Fixed problem with gripper model
    [ur5_egomo_table.urdf]
2016-06-01 Changed Gripper model in Xacro
    [ur5_egomo_table.urdf.xacro]
2016-06-01 Joint state of the gripper is now published. TODO: Fix outliers of pos_fb
    [ros_egomo_node.lua]
2016-06-13 Prepared action for actionlib support for gripper
2016-06-13 start to modularize
    [ur5_egomo_table.urdf, ur5_egomo_table.urdf.xacro]
2016-06-14 Sending gripper commands via action_lib and add commands for Laser/LED. TODO: Test both and validate results.
2016-06-15 Added information about object has been gripped to message and rename service as not only responsible for gripper commands.
2016-06-15 - Added state, object_gripped to Gripper message - Added speed, force and setting flag to gripper action - Added support for Gripper commands using actions - Added detection of success of gripping
2016-06-16 Added action for gripper activation and added object_gripped field to result of gripping action.
2016-06-16 Added deactivation of the gripper using an action
2016-06-16 - Added alias for light (laser, ir-laser, led) commands. (TODO: validate) - Removed unused code - Removed unused variables
2016-06-17 structured urdf files with new xacros.
    [default_egomo_sensor_parameters.xacro, default_ur5_DH_parameters.xacro, egomo_sensor.urdf.xacro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]
2016-06-17 clean up
    [ur5_egomo_table_ori.urdf.xacro]
2016-06-17 Add egomo_3d_printed_parts
    [xamla_cap.stl, xamla_cap_hole.stl, xamla_mount_base.stl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]
2016-06-17 Adds the Xamla IOBoard specs, pinout and schematic
2016-06-20 relaxed limits in shoulder pan joint
    [ur5_robot.urdf.xacro]
2016-06-21 Add images of sensor head assembly
2016-06-22 relaxed sholder joint limits
    [ur5_robot.urdf.xacro]
2016-07-26 relaxed jointlimits in wristjoints
    [ur5_robot.urdf.xacro]
2016-07-29 moved tool0 to gripper tip
    [ur5_egomo_table.urdf.xacro]
2017-02-10 Add error printout
2017-03-08 Adopt clearTable demo to current setup
2017-03-10 corrected xacro definition
    [default_egomo_sensor_parameters.xacro, default_ur5_DH_parameters.xacro, robotiq_85_gripper.urdf.xacro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]
2017-03-10 eliminated most of the xacro warnings
    [default_ur5_DH_parameters.xacro, egomo_sensor.urdf.xacro]
